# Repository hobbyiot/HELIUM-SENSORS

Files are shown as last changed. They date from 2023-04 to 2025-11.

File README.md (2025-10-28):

# HELIUM-SENSORS
## Helium IoT Network Sensor Development board | [H2S-Dev V1.2](https://github.com/hobbyiot/HELIUM-SENSORS/tree/main/H2S-Dev%20V1.2)

H2S-Dev board is a ready-to-use, Open source hardware, Arduino compatible, LoRaWAN Helium network sensor development board. It is capable of implementing a number of sensor and positioning applications. The board is mainly targeted to makers and hobbyists.

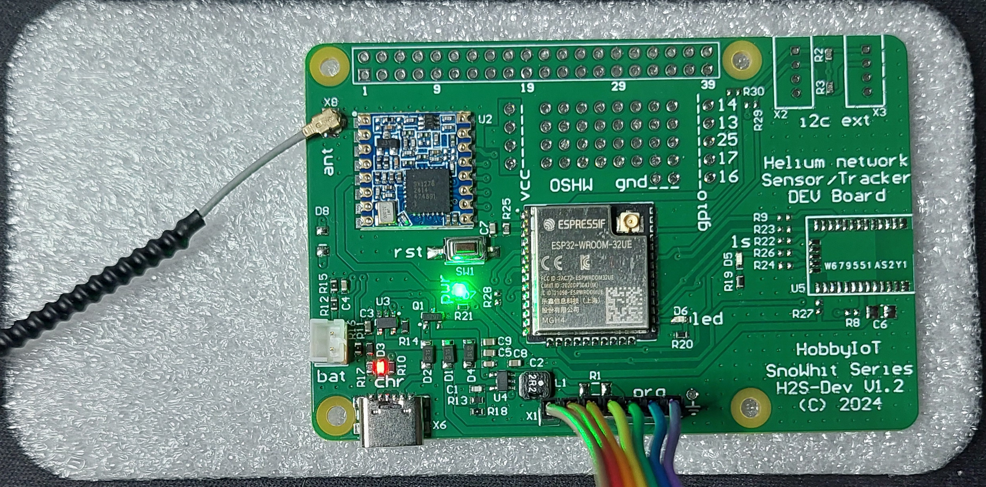
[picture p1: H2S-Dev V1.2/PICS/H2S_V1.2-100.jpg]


H2S-Dev board key features and flexible assembly options including ESP32 and SX1276 LoRa worldwide modules as well as optional GNSS. A practical powering circuitry is implemented that is capable of powering the board from the programming interface, USB-C and/or RPi compatible connector. The LiPo battery controller also charges the battery connected. The soldering area and I2C extensions allow wiring of sensors and connecting devices via I2C interfaces.

The most recent version of the Helium IoT Network Sensor Development board (H2S-Dev) is V1.2

https://github.com/hobbyiot/HELIUM-SENSORS/tree/main/H2S-Dev%20V1.2

---

### [This project was sponsored by PCBWay in 2024](https://github.com/hobbyiot/HELIUM-SENSORS/blob/main/README.md#this-project-was-sponsored-by-pcbway).

### [Levcoin donations are welcome, Bitcoin (BTC) and Helium (HNT) are accepted](https://github.com/hobbyiot/HELIUM-SENSORS/blob/main/README.md#crypto-donations).

---

H2S-Dev board is built around ESP32 MCU module and LoRaWAN SX1276 based radio module, supporting worldwide radio frequency bands, I2C standard interfaces for connecting various sensors and the relatively cheap integrated GNSS module with small chip antenna on it.

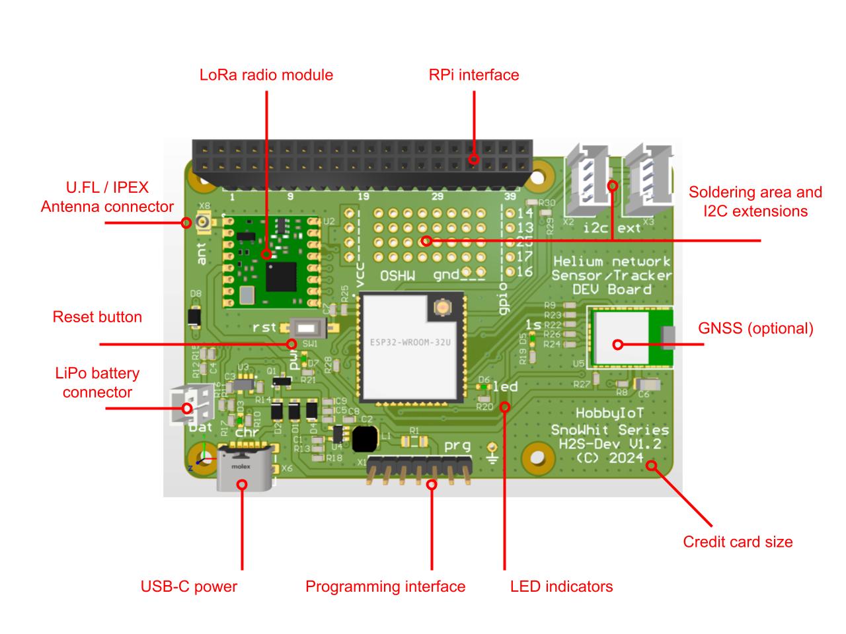
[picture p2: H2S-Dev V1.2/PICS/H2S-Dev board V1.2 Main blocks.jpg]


The development board also incorporates a standard 7-pin ESP32 serial programming interface to use with any compatible Serial to USB adapter. Set of LED indicators - Power, “1 second” GNSS, Charging and General purpose LEDs are on board for indicating certain activities. USB-C and LiPo battery sockets are available for dual powering with charging circuitry and battery level sensing line routed to a CPU GPIO pin. There is also a development area grid - holes matrix area (4 rows x 8 holes each, 0.1 inch / 2.54 mm pitch) with power and ground points nearby for adding sensors, interfaces, and add-ons. Several GPIOs are routed close to the matrix area.

### Technical parameters
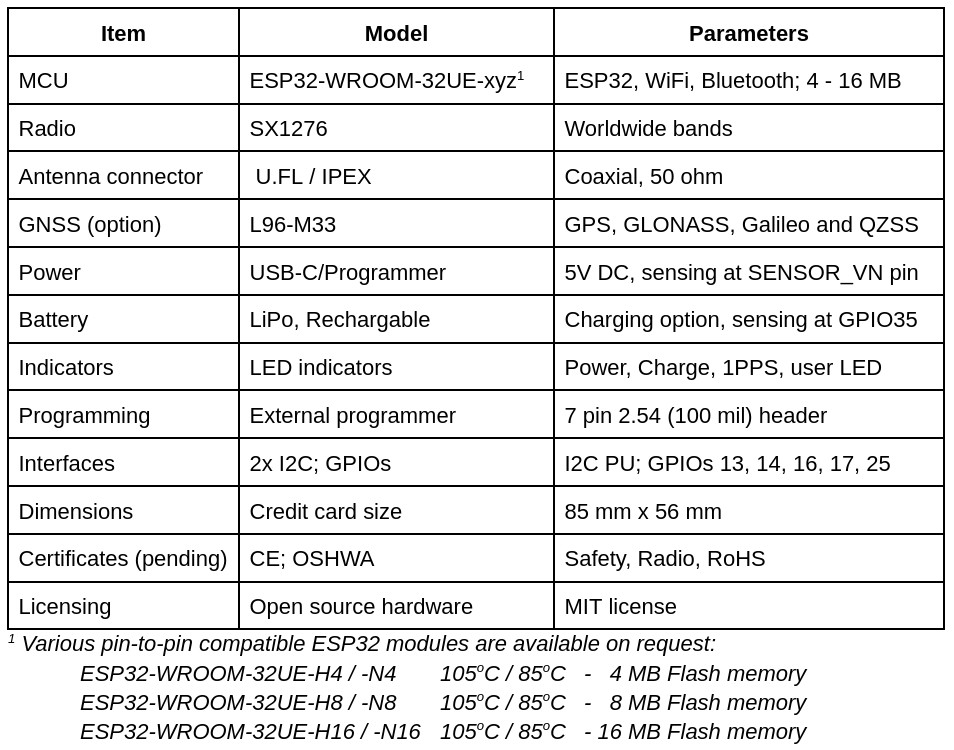
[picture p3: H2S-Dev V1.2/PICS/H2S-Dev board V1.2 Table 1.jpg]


### Circuit schematic
The circuit schematic of the Helium IoT Network Sensor Development board (H2S-Dev V1.2) is shown in the picture below. Central area presents the MCU and optional GNSS module together with the LoRa radio module and antenna connector.

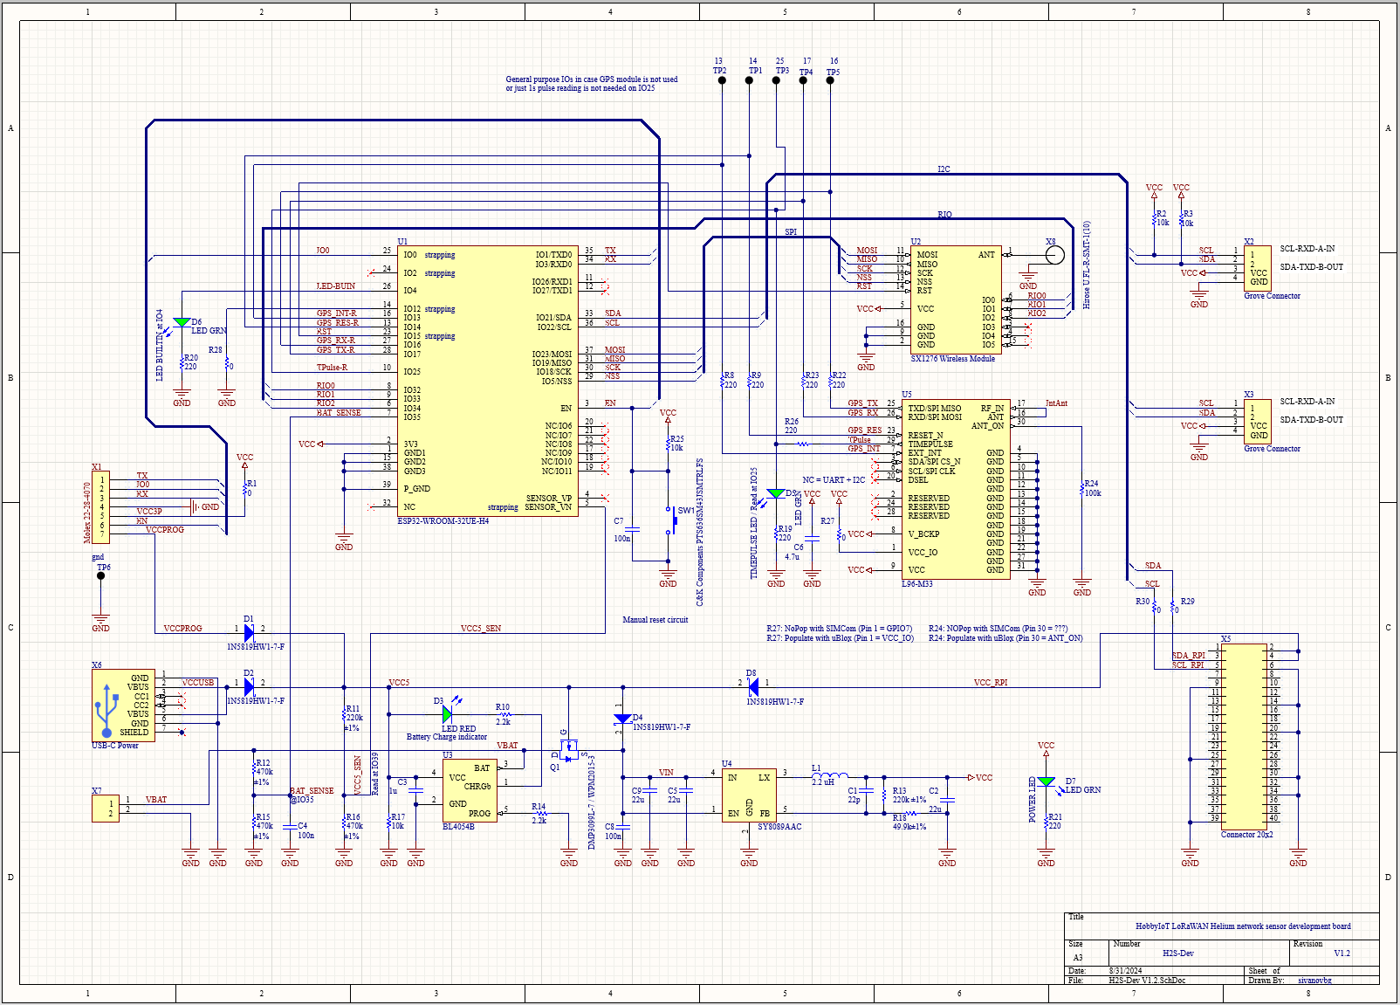
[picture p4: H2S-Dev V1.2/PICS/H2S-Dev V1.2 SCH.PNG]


On the left the mandatory I/O interface connectors are situated. Right part consists of the optional connectors. On the bottom part of the sheet the battery input and charging circuitry are placed together with the DC/DC converter responsible for generating the supply voltage for the entire design. LED indicators and a Reset switch are placed according to their corresponding function.

The schematic is drawn on a A3 standard page. Detailed schematic in PDF format: [H2S-Dev V1.2 Schematic](https://github.com/hobbyiot/HELIUM-SENSORS/blob/main/H2S-Dev%20V1.2/HW/H2S-Dev%20V1.2%20Schematic.pdf)

### Printed Circuit board

The printed circuit board (PCB) of the Helium IoT Network Sensor Development board (H2S-Dev V1.2) is designed to use a standard FR-4 1.6 mm 2-layer material for production.

H2S-Dev V1.2 Top Layer     |  H2S-Dev V1.2 Bottom Layer
:-------------------------:|:-------------------------:
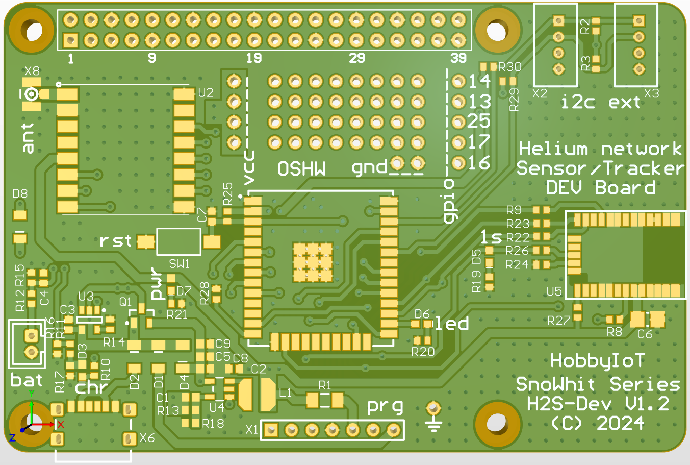
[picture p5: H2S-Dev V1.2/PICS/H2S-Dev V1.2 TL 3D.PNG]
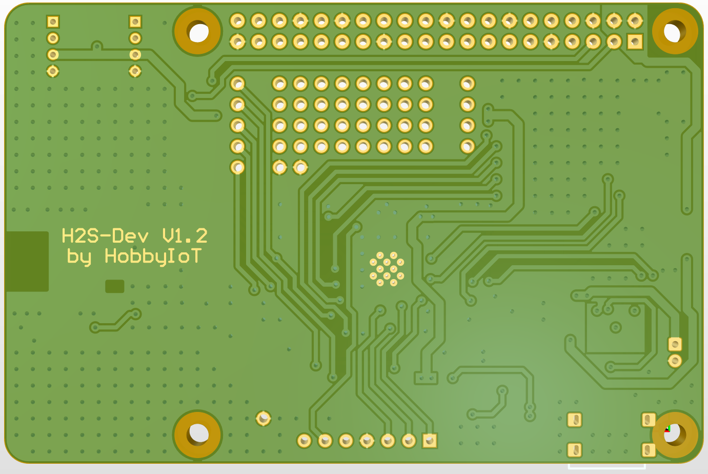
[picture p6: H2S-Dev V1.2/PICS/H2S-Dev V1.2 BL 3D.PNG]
  |  

Main parts are situated for convenient operation and minimal interference between radios implemented. The LoRa module pin 1 to U.FL antenna small trace is routed with a special attention to ensure the 50 ohm impedance requirement of that trace. The GNSS module is far away, on the other edge of the board, and it is surrounded by solid copper regions on both top and bottom copper layers according to the recommendations for proper reception of the satellite signals by the small chip antenna.

The JST battery connector and USB-C power socket are situated on the down left of the board close to the corresponding circuitry. Programming interface is a 7-pin header for connecting a suitable module to burn a software sketch into the MCU via serial interface.

On the top of the board 2x20 connector and Groove compatible footprints are located. Both of them carry powering and I2C interfaces.

### H2S-Dev board V1.2 assembly variants


### H2S-Dev board V1.2 Arduino code example

This example code in (H2S-DEV-THS-V0.1.ino) sends a valid LoRaWAN packet over The Helium network with a payload containing temperature and humidity data as they are read from a DHT11 sensor, connected to GPIO13 using frequency and encryption settings according your region.

More information: https://github.com/hobbyiot/HELIUM-SENSORS/tree/main/H2S-Dev%20V1.2/SW

The hardware of the Helium IoT Network Sensor Development board V1.2 is designed as an open source project in the Altium Circuit Maker environment. To access the project follow the links below.

https://workspace.circuitmaker.com/Projects/Details/sivanovbg/H2S-Dev-V12

https://365.altium.com/files/AC741A32-A420-4803-868D-E6CB6756A587

---

#### This project was sponsored by PCBWay.

#### They offer a turnkey service to manufacture and assemble your printed circuit boards! The whole operation is fast and reliable since every single step is agreed between the customer and the responsible people from the factory. Every one detail is discussed as the components and materials used are agreed on at a high professional level.
#### Ordering of the boards and assembly service is easy to use and fully automated through the PCBWay website and is conducted smoothly. The forwarding options are fast and flexible to have your prototypes on time!

#### I am quite impressed with the way of work and communication with the PCBWay team. The communication is fast and focused on the customer's needs. I also found PCBWay conducts various contests and grows an open source hardware community! There is even a possibility to review and order an open source project, included by a developer on the PCBWay store!

#### Thank you, PCBWay and your friendly team! I hope I will keep working with!

---

### And one more thing… Technologies and services are important, but the most important are people you are working with.

---

### Crypto donations

Crypto | Wallet address
:-------------------------------:|:----------------------------------------------------------------------:
[Levcoin](https://levcoin.net/) | <small>bg2HVDv6r9VhCi2fR8QeBy5VAgbcav7YY3yypi6ugYoBFXgFmqjQGKWjm7LZrsRQx488v58UjnYXRNdQKU5vjsiA2Yj1kNtYZ</small>
Bitcoin (BTC) | bc1q0l2zv2ayns5ppz6v9xnggkjyskdt0ywgk6zsck
Helium (HNT) | 9Un8EUQdXY53rSst26B5tufz9FUZbhcfqTYNMr4AuATh

---

https://www.pcbway.com/ | https://www.hobbyiot.net/
:----------------------------:|:------------------------------:
https://x.com/HobbyIoT | https://www.patreon.com/HobbyIoT

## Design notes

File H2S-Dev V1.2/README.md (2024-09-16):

# Helium IoT Network Sensor Development board | H2S-Dev V1.2
## Main changes and improvements

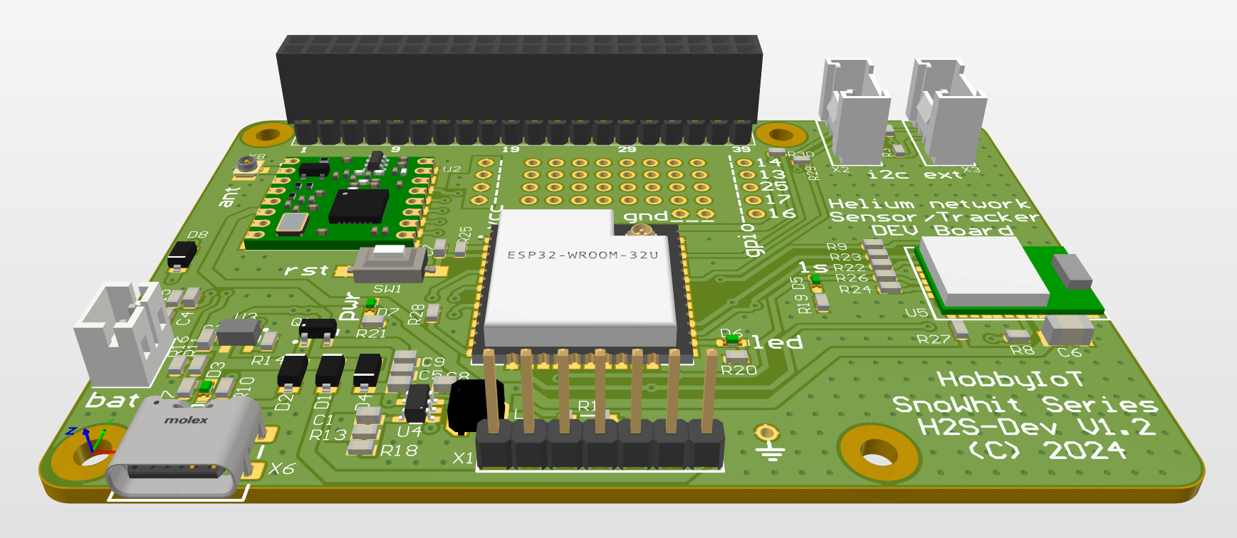
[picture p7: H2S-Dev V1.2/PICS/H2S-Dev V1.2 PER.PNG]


- A U.FL connector has been replaced the fixed LoRa spring antenna to improve the flexibility for the developers to connect most suitable antenna according the radio power and frequency requirements;

- A Basic variant of the development board has been defined as a cheap version of the PCB to improve cost effectiveness and design flexibility;

- A Full variant of the development board is now including GNSS module that gives the development of a Helium based GNSS tracking device a kick start to test the application

The project targets a LoRaWAN device - Helium IoT Network Sensor Development board (H2S-Dev) product with GNSS tracking option for primary usage with the LoRaWAN based Helium network. The board is mainly targeted to makers and hobbyists.

It’s built around ESP32 MCU module and LoRaWAN SX1276 based radio module, supporting worldwide radio frequency bands, I2C standard interfaces for connecting various sensors and the relatively cheap integrated GNSS module with small chip antenna on it. The development board also incorporates a standard 7-pin ESP32 serial programming interface to use with any compatible Serial to USB adapter. Set of LED indicators - Power, “1 second” GNSS, Charging and General purpose LEDs are on board for indicating certain activities. USB-C and LiPo battery sockets are available for dual powering with charging circuitry and battery level sensing line routed to a CPU GPIO pin. There is also a development area grid - holes matrix area (4 rows x 8 holes each, 0.1 inch / 2.54 mm pitch) with power and ground points nearby for adding sensors, interfaces, and add-ons. Several GPIOs are routed close to the matrix area.
#
More information: [H2S-Dev board V1.2 Hardware description and features](https://github.com/hobbyiot/HELIUM-SENSORS/blob/main/H2S-Dev%20V1.2/H2S-Dev%20board%20V1.2%20Hardware%20description%20and%20features.pdf)

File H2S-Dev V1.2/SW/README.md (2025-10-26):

## H2S-Dev with DHT11 temperature and humidity sensor example

The most recent example code in ([H2S-DEV-THS-V0.5.ino](https://github.com/hobbyiot/HELIUM-SENSORS/blob/main/H2S-Dev%20V1.2/SW/H2S-DEV-THS-V0.5.ino)) sends a valid LoRaWAN packet over The Helium network with a payload containing temperature and humidity data as they are read from a DHT11 sensor, connected to GPIO#13 using frequency and encryption settings according your region.

You can solder and wire the DHT11 sensor within the H2S-Dev soldering area or just use Crowtail connector directly to the H2S-Dev board using the [Elecrow DHT11 sensor module](https://www.elecrow.com/crowtail-temperature-humidity-sensor-p-1229.html).

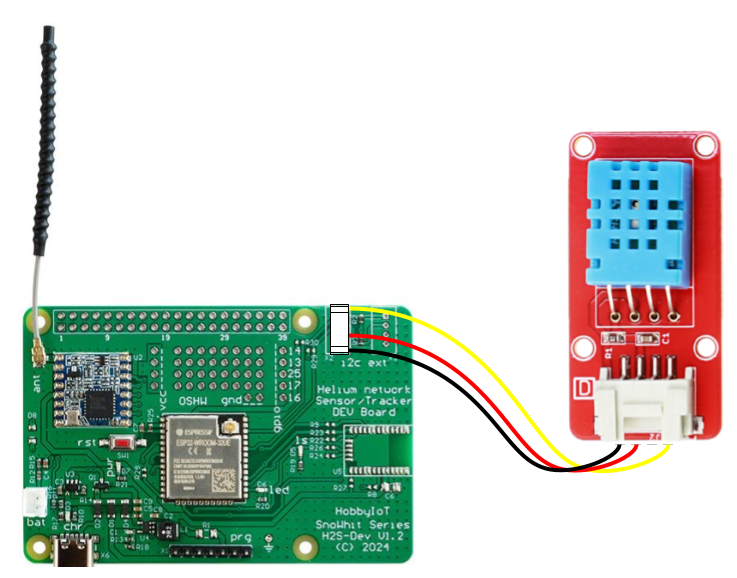
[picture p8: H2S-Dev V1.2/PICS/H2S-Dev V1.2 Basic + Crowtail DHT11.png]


The data format and the JSON script for decoding it will be soon described in separate article in the project's GitHub (https://github.com/hobbyiot/HELIUM-SENSORS)

You can also direct the received data via Helium console directly to a Google sheet!

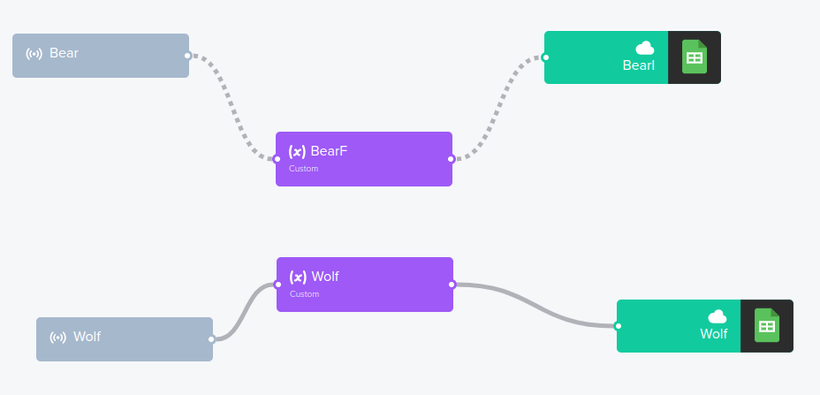
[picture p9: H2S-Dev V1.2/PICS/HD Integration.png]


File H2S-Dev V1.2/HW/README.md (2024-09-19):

# Helium IoT Network Sensor Development board | H2S-Dev V1.2
## Hardware review

### Circuit schematic

The circuit schematic of the Helium IoT Network Sensor Development board (H2S-Dev V1.2) is shown on the picture below. Central area presents the MCU and optional GNSS module together with the LoRa radio module and antenna connector.



On the left the mandatory I/O interface connectors are situated. Right part consists the optional connectors. On the bottom part of the sheet the battery input and charging circuitry are placed together with the DC/DC converter responsible for generating the supply voltage for the entire design. LED indicators and a Reset switch are placed according to their corresponding function.

The schematic is drawn on a A3 standard page. Detailed schematic in PDF format: [H2S-Dev V1.2 Schematic](https://github.com/hobbyiot/HELIUM-SENSORS/blob/main/H2S-Dev%20V1.2/HW/H2S-Dev%20V1.2%20Schematic.pdf)

### Printed Circuit board

The printed circuit board (PCB) of the Helium IoT Network Sensor Development board (H2S-Dev V1.2) is designed to use a standard FR-4 1.6 mm 2-layer material for production.

H2S-Dev V1.2 Top Layer     |  H2S-Dev V1.2 Bottom Layer
:-------------------------:|:-------------------------:
  |  

Main parts are situated for convenient operation and minimal interference between radios implemented. The LoRa module pin 1 to U.FL antenna small trace is routed with a special attention to ensure the 50 ohm impedance requirement of that trace. The GNSS module is far away, on the other edge of the board, and it is surrounded by solid copper regions on both top and bottom copper layers according the recommendations for proper reception of the satellite signals by the small chip antenna.

JST battery connector and USB-C power socket are situated on the down left of the board close to the corresponding circuitry. Programming interface is a 7-pin header for connecting a suitable module to burn a software sketch into the MCU via serial interface.

On the top of the board 2x20 connector and Groove compatible footprints are located. Both of them carry powering and I2C interfaces.

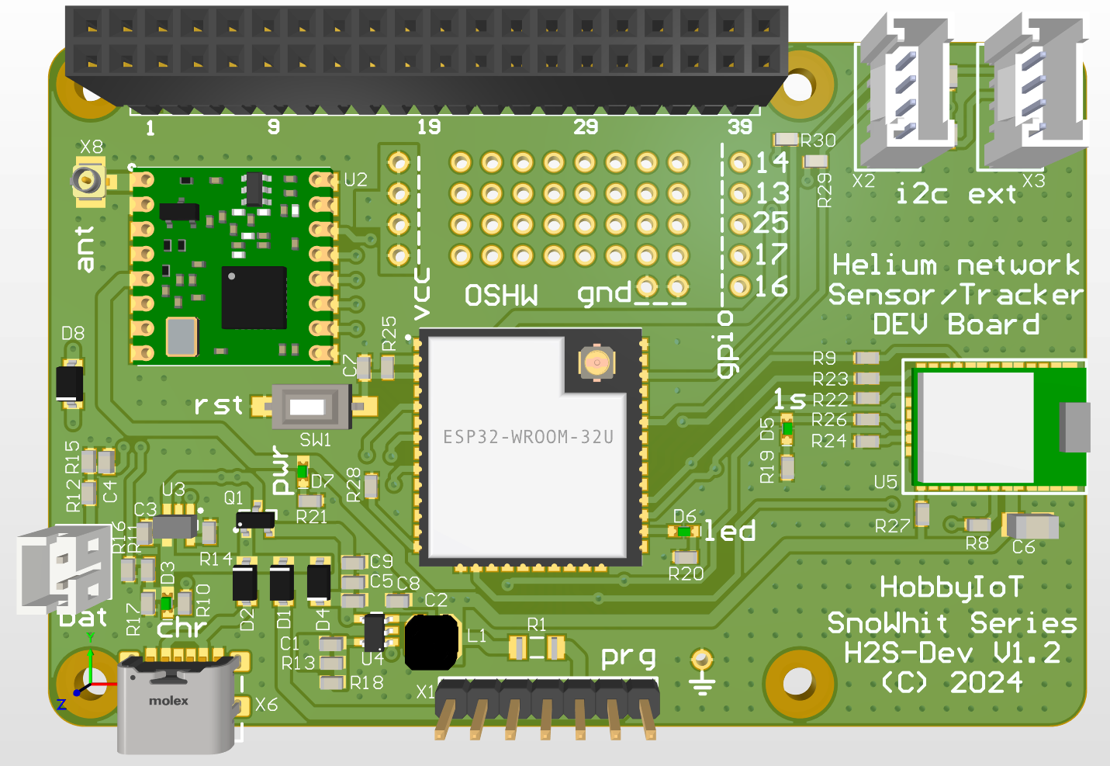
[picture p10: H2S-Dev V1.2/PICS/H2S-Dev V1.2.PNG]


The size, mechanics and 2x20 connector nets of the Helium IoT Network Sensor Development board V1.2 comply with the recent RaspberryPi specifications.

#
The hardware of the Helium IoT Network Sensor Development board V1.2 is designed as an open source project in the Altium Circuit Maker environment. To access the project follow the links below.

https://workspace.circuitmaker.com/Projects/Details/sivanovbg/H2S-Dev-V12

https://365.altium.com/files/AC741A32-A420-4803-868D-E6CB6756A587
#
More information: [H2S-Dev board V1.2 Hardware description and features](https://github.com/hobbyiot/HELIUM-SENSORS/blob/main/H2S-Dev%20V1.2/H2S-Dev%20board%20V1.2%20Hardware%20description%20and%20features.pdf)

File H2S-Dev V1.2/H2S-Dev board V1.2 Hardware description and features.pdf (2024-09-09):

### H2S-Dev board

LoRaWAN Helium network sensor development board V1.2
Hardware description and features

Introduction

H2S-Dev board is a ready-to-use, Open source hardware, Arduino compatible, LoRaWAN Helium network sensor development board. It is capable of implementing a number of sensor and positioning applications.

H2S-Dev board key features and flexible assembly options including ESP32 and SX1276 LoRa worldwide modules as well as optional GNSS. A practical powering circuitry is implemented that is capable of powering the board from the programming interface, USB-C and/or RPi compatible connector. The LiPo battery controller also charges the battery connected. The soldering area and I2C extensions allow wiring of sensors and connecting devices via I2C interfaces.

H2S-Dev board is following the Raspberry Pi form factor (credit card size) with mounting holes and 40-pin connector including power and I2C traces for further development.

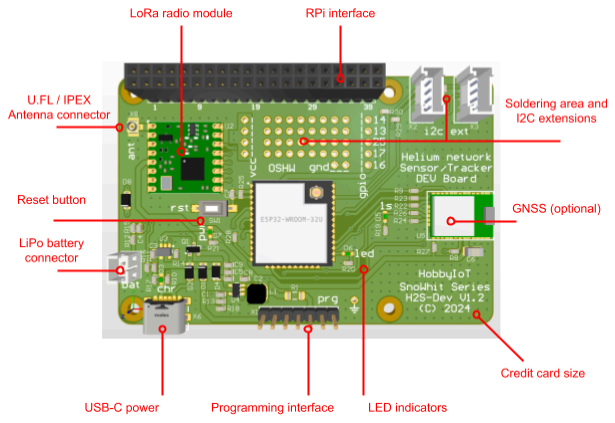
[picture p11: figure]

More information: https://www.hobbyiot.net | 1

Hardware description

H2S-Dev board V1.2 is the new upcoming improved version with flexible assembly variants. It contains ESP32, LoRa radio with 50 ohm U.FL/IPEX connector for various frequency bands, optional GNSS, powering options and interfaces resulting in a rich set of features. That open source hardware platform is ready for one to quickly set up an application, connect sensors and test IoT data transfer over the Helium LoRaWAN network.

ESP32 WROOM MCU runs the device application software. It controls the LoRa radio module via SPI interface and I/O signals required. MCU also connects to the optional GNSS module via UART interface and control lines. When GNSS is not used, a number of GPIO lines are free for connecting additional sensors. These lines are routed close to the development area of the board. WiFi and Bluetooth are available with an external antenna. Pin-to-pin compatible modules are available up to the application requirements including H4/N4 (4 MB Flash) up to H16/N16 (16 MB Flash).

The LoRa Radio module establishes the connection to the Helium LoRaWAN network. It is built around SX1276 IC and connects to the MCU via SPI interface as described. Radio module requires an antenna to operate and the antenna should be in place before powering on the module to prevent radio amplifier damage. Size and type of the antenna depends on the gain required and the specific frequency band for the region. Antenna connector type is U.FL / IPEX.

GNSS module (optional) - when assembled, the GNSS module connects to the MCU via UART interface. Once locked to satellites it provides date/time and positioning information to the system and the 1PPS LED will flash every one second. The dev board PCB topology is designed according to the GNSS module recommendations to ensure proper signal reception by the onboard chip-antenna.

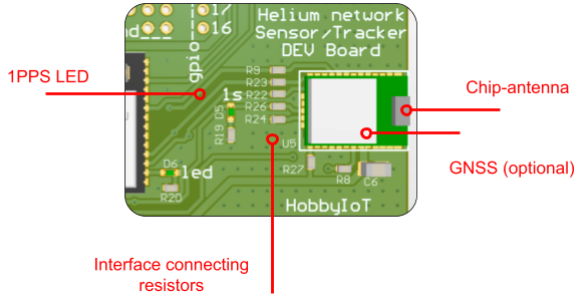
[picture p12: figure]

More information: https://www.hobbyiot.net | 2

Soldering area and I2C extensions - That area is especially dedicated to developers. It contains 4 rows by 8 columns of THT mounting holes with 2.54 mm (100 mil) spacing as well as I2C extensions.

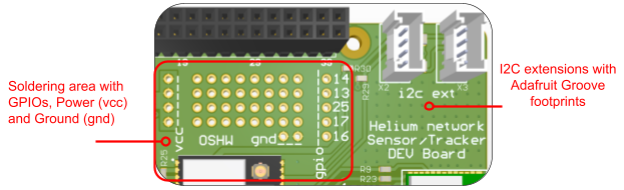
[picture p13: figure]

One can solder connection headers, small sensors and any other external devices into that area. Close to that pattern a 3.3V power (vcc) and Ground (gnd) connection points are available. Also, several MCU I/O signals are routed around that area for easy interfacing with the MCU.

I2C extensions (i2c ext) provide an I2C interface together with 3.3V and GND. Footprint and pinout are compatible with Adafruit Groove specifications. 4.7 k pull up resistors are populated on the dev board.

Programming interface - these pins are used to program and debug the software into the dev board. Pinout is compatible with the Olimex ESP32 programmer board as shown below. Using such a programmer the ESP32 is entering programing mode automatically when the upload attempt is initiated from the programming environment.

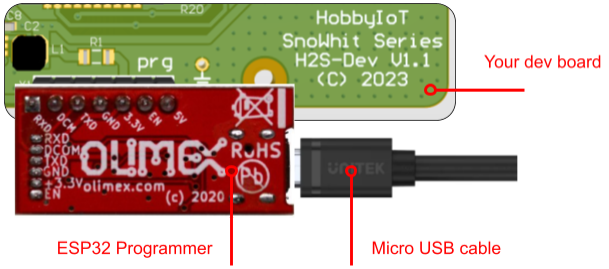
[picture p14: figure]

More information: https://www.hobbyiot.net | 3

Important notice! When connecting the programmer, first connect it to the dev board and after that connect the micro usb cable as shown in the picture below.

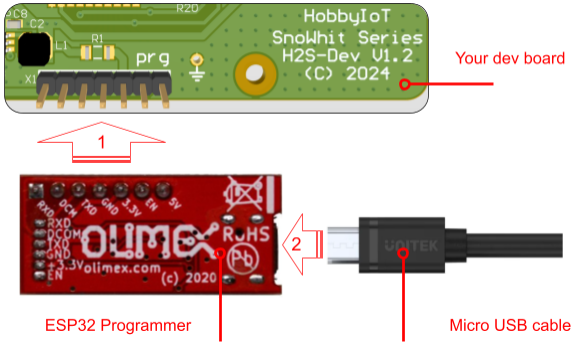
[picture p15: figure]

LiPo battery connector JST type, 2-pole socket is used to connect a LiPo battery to independently power the dev board. The circuitry behind is built around the LiPo battery controller BL4054B and DC/DC converter SY8088AAC and will automatically switch to battery power when other sources are down. Connected battery will also be charged if any of the other power sources are connected. Battery voltage can be read by the user software at GPIO35 and the external voltage presence trigger level is available at GPIO39 via resistor dividers.

USB-C power - 5V DC power only input using USB-C standard cable.

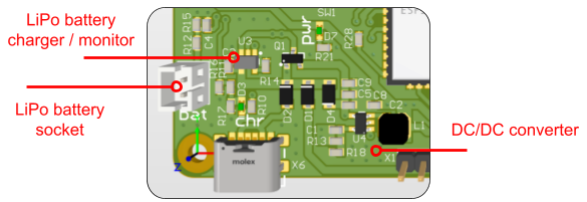
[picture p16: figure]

More information: https://www.hobbyiot.net | 4

RPi interface - As a future use the dev board could be connected and powered as a Raspberry Pi HAT. I2C, power and GND lines are routed to that connector.

Reset button - Used to perform hardware reset of the board.

Credit card size - The dev board dimensions are 85 mm x 56 mm and carries 4 mounting holes compatible with Raspberry Pi.

Technical parameters

Item | Model | Parameters
MCU | ESP32-WROOM-32UE-xyz 1 | ESP32, WiFi, Bluetooth; 4 - 16 MB
Radio | SX1276 | Worldwide bands
Antenna connector | U.FL / IPEX | Coaxial, 50 ohm
GNSS (option) | L96-M33 | GPS, GLONASS, Galileo and QZSS
Power | USB-C/Programmer | 5V DC, sensing at SENSOR_VN pin
Battery | LiPo, Rechargable | Charging option, sensing at GPIO35
Indicators | LED indicators | Power, Charge, 1PPS, user LED
Programming | External programmer | 7 pin 2.54 (100 mil) header
Interfaces | 2x I2C; GPIOs | I2C PU; GPIOs 13, 14, 16, 17, 25
Dimensions | Credit card size | 85 mm x 56 mm
Certificates (pending) | CE; OSHWA | Safety, Radio, RoHS
Licensing | Open source hardware | MIT license

### 1 Various pin-to-pin compatible ESP32 modules are available on request:

ESP32-WROOM-32UE-H4 / -N4 105 oC / 85

oC - 4 MB Flash memory
ESP32-WROOM-32UE-H8 / -N8 105 oC / 85

oC - 8 MB Flash memory
ESP32-WROOM-32UE-H16 / -N16 105
| oC / 85

oC - 16 MB Flash memory

H2S-Dev board V1.2 assembly variants

Variant name | Variant description
H2S-Dev board Basic | ESP32, LoRa, no GNSS module, 5x GPIOs, 2x I2C, LED indicators
H2S-Dev board Full | ESP32, LoRa, L96-M33 GNSS module, 2x I2C, LED indicators
More information: https://www.hobbyiot.net | 5

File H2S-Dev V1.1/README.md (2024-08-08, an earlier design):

# Helium IoT Network Sensor Development board
Version 1.1

H2S-Dev V1.1

The project targets a LoRaWAN device - Helium IoT Network Sensor Development board (H2S-Dev) product with GNSS tracking option for primary usage with the LoRaWAN based Helium network. The board is mainly targeted to makers and hobbyists.
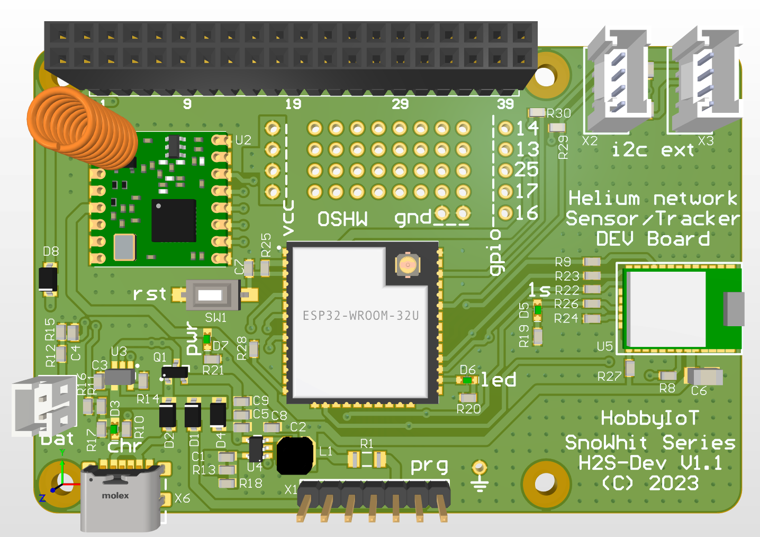
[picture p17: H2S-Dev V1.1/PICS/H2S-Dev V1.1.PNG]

It’s built around ESP32 MCU module and LoRaWAN SX1276 based radio module, supporting worldwide radio frequency bands, I2C standard interfaces for connecting various sensors and the relatively cheap integrated GNSS module with small chip antenna on it. The development board also incorporates a standard 7-pin ESP32 serial programming interface to use with any compatible Serial to USB adapter. Set of LED indicators - Power, “1 second” GNSS, Charging and General purpose LEDs are on board for indicating certain activities. USB-C and LiPo battery sockets are available for dual powering with charging circuitry and battery level sensing line routed to a CPU GPIO pin. There is also a development area grid - holes matrix area (4 rows x 8 holes each, 0.1 inch / 2.54 mm pitch) with power and ground points nearby for adding sensors, interfaces, and add-ons. Several GPIOs are routed close to the matrix area.

More information: [H2S-Dev board Hardware description and features](https://github.com/hobbyiot/HELIUM-SENSORS/blob/main/H2S-Dev%20V1.1/DOCS/H2S-Dev%20board%20Hardware%20description%20and%20features.pdf)

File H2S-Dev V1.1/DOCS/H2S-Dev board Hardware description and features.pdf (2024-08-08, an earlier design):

### H2S-Dev board

LoRaWAN Helium network sensor development board V1.1
Hardware description and features

Introduction

H2S-Dev board is a ready-to-use, Open source hardware, Arduino compatible, LoRaWAN Helium network sensor development board. It is capable of implementing a number of sensor and positioning applications.

H2S-Dev board key features include ESP32 and SX1276 LoRa modules as well as optional GNSS. A practical powering circuitry is implemented that is capable of powering the board from the programming interface, USB-C and RPi compatible connector. The LiPo battery controller also charges the battery connected. The soldering area and I2C extensions allow placing of sensors and connecting devices via I2C interfaces.

H2S-Dev board is following the Raspberry Pi form factor (credit card size) with mounting holes and 40-pin connector including power and I2C traces for further development.

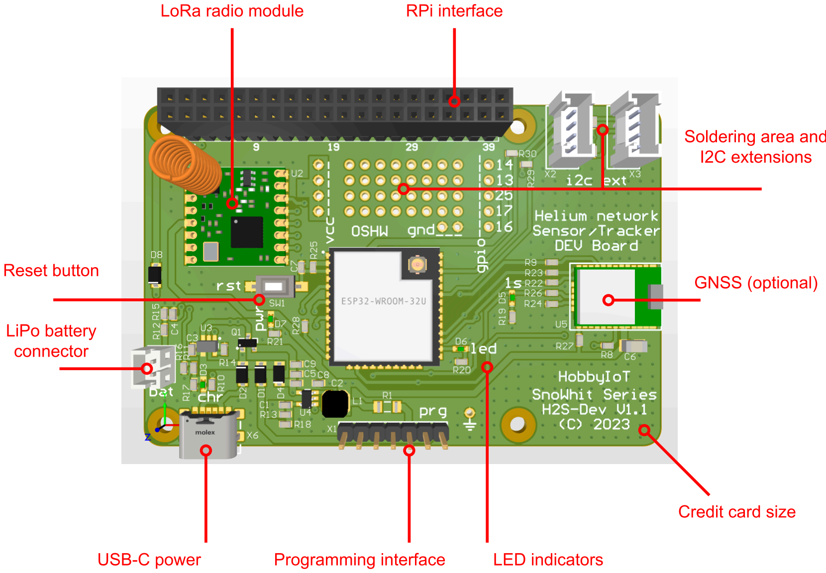
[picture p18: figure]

Hardware description

H2S-Dev board current version is V1.1. It contains ESP32, LoRa radio, optional GNSS, powering options and interfaces resulting in a rich set of features. That open source hardware platform is ready for one to quickly set up an application, connect sensors and test IoT data transfer over the Helium LoRaWAN network.

Main hardware parts are described below.

ESP32 WROOM MCU runs the device application software. It controls the LoRa radio module via SPI interface and I/O signals required. MCU also connects to the optional GNSS module via UART interface and control lines. When GNSS is not used, a number of GPIO lines are free for connecting additional sensors. These lines are routed close to the development area of the board. WiFi and Bluetooth are available with an external antenna.

The LoRa Radio module establishes the connection to the Helium LoRaWAN network. It is built around SX1276 IC and connects to the MCU via SPI interface as described. Radio module requires an antenna to operate and the antenna should be in place before powering on the module to prevent radio amplifier damage. Size and type of the antenna depends on the gain required and the specific frequency band for the region.

GNSS module (optional) - when assembled, the GNSS module connects to the MCU via UART interface. Once locked to satellites it provides date/time and positioning information to the system and the 1PPS LED will flash every one second. The dev board PCB topology is designed according to the GNSS module recommendations to ensure proper signal reception by the onboard chip-antenna.

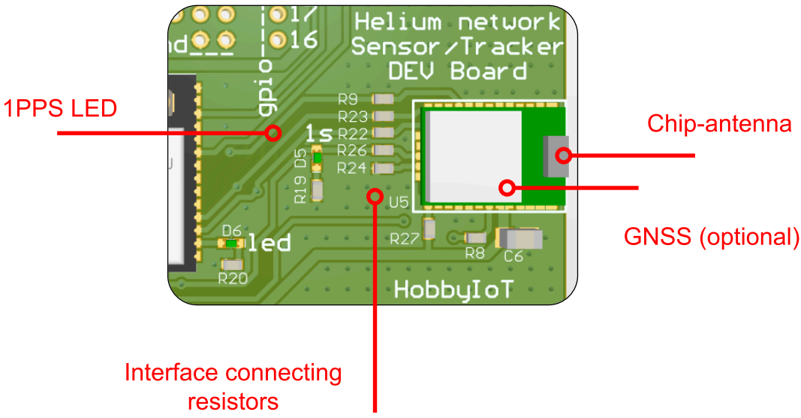
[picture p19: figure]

Soldering area and I2C extensions - That area is especially dedicated to developers. It contains 4 rows by 8 columns of THT mounting holes with 2.54 mm (100 mil) spacing as well as

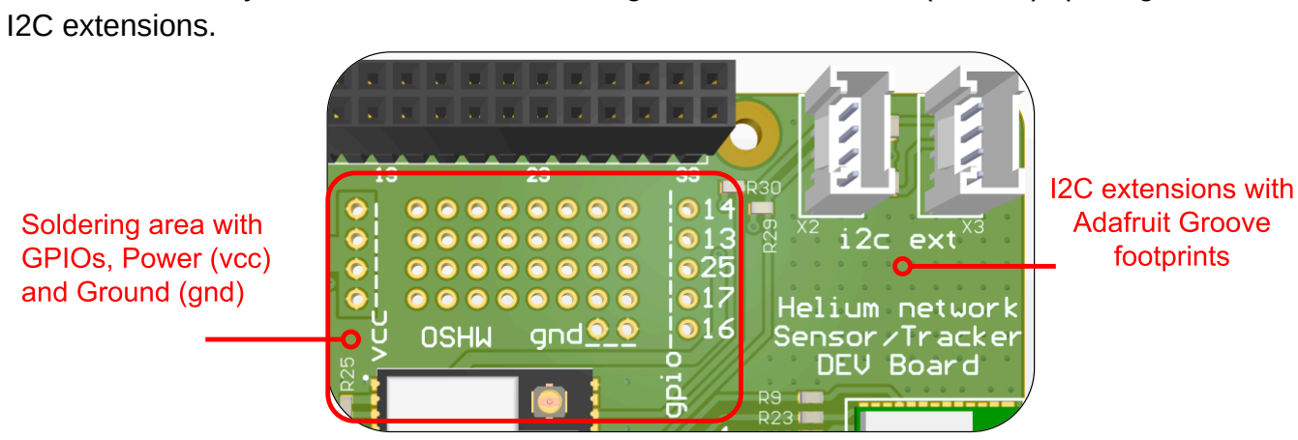
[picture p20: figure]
I2C extensions.

One can solder connection headers, small sensors and any other external devices into that area. Close to that pattern a 3.3V power (vcc) and Ground (gnd) connection points are available. Also, several MCU I/O signals are routed around that area for easy interfacing with the MCU.

I2C extensions (i2c ext) provide an I2C interface together with 3.3V and GND. Footprint and pinout are compatible with Adafruit Groove specifications. 4.7 k pull up resistors are populated on the dev board.

Programming interface - these pins are used to program and debug the software into the dev board. Pinout is compatible with the Olimex ESP32 programmer board as shown below. Using such a programmer the ESP32 is entering programing mode automatically when the upload attempt is initiated from the programming environment.

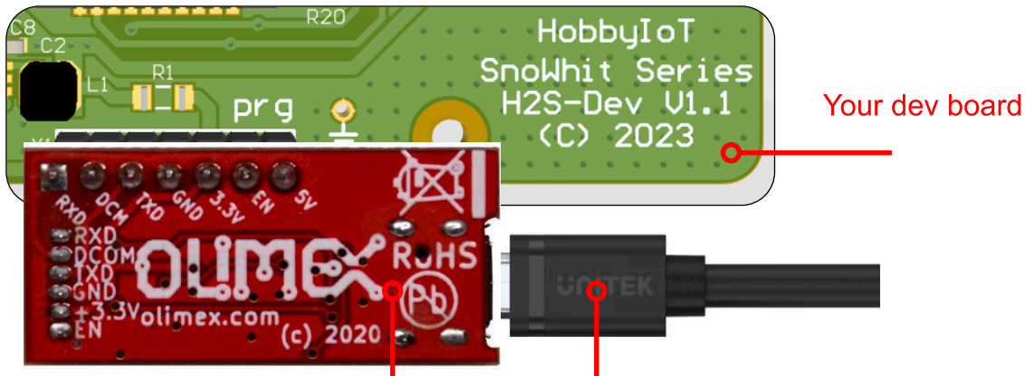
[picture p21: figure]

Important notice! When connecting the programmer, first connect it to the dev board and after that connect the micro usb cable as shown in the picture below.

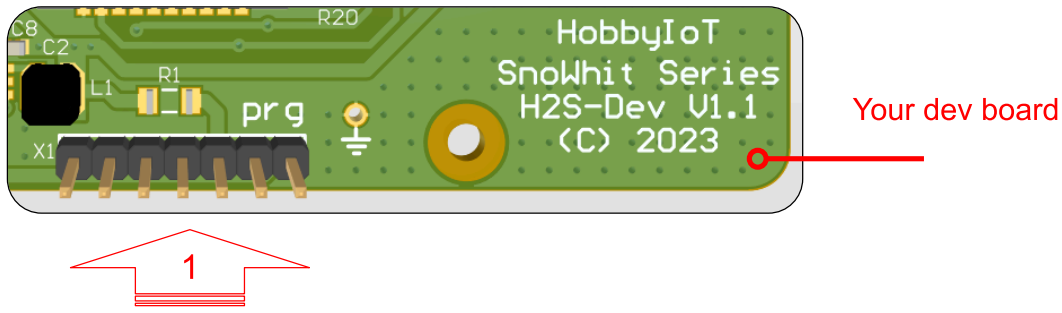
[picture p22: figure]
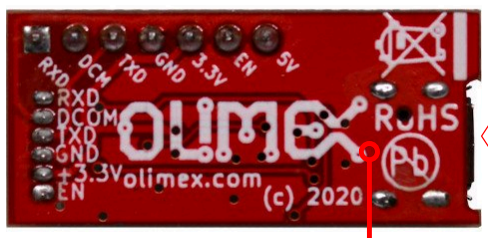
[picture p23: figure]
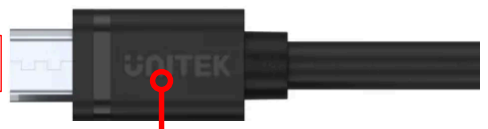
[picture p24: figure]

LiPo battery connector JST type, 2-pole socket is used to connect a LiPo battery to independently power the dev board. The circuitry behind is built around the LiPo battery controller BL4054B and DC/DC converter SY8088AAC and will automatically switch to battery power when other sources are down. Connected battery will also be charged if any of the other power sources are connected. Battery voltage can be read by the user software at GPIO35 and the external voltage presence trigger level is available at GPIO39 via resistor dividers.

USB-C power - 5V DC power only input using USB-C standard cable.

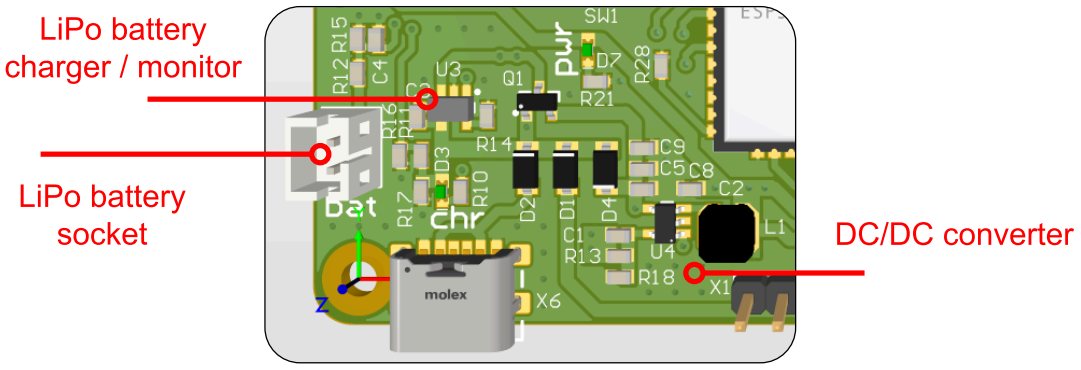
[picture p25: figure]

RPi interface - As a future use the dev board could be connected and powered as a Raspberry Pi HAT. I2C, power and GND lines are routed to that connector.

Reset button - Used to perform hardware reset of the board.

Credit card size - The dev board dimensions are 85 mm x 56 mm and carries 4 mounting holes compatible with Raspberry Pi.

Technical parameters

Item | Model | Parameters
MCU | ESP32 WROOM Series | ESP32, WiFi, Bluetooth
Radio | SX1276 with spring antenna | Worldwide bands
GNSS (option) | L96-M33 | GPS, GLONASS, Galileo and QZSS
Power | USB-C/Programmer | 5V DC
Battery | LiPo, Rechargable | Charging/sensing circuitry
Indicators | LED indicators | Power, Charge, 1PPS, user LED
Programming | External programmer | 7 pin 2.54 (100 mil) header
Interfaces | 2x I2C; GPIOs | I2C PU; GPIOs 13, 14, 16, 17, 25
Dimensions | Credit card size | 85 mm x 56 mm
Certificates (pending) | CE; OSHWA | Safety, Radio, RoHS
Licensing | Open source hardware | MIT license

More information

Github: https://github.com/hobbyiot/HELIUM-SENSORS

X/Twitter: https://x.com/HobbyIoT

Patreon: https://www.patreon.com/HobbyIoT

Web: https://www.hobbyiot.net

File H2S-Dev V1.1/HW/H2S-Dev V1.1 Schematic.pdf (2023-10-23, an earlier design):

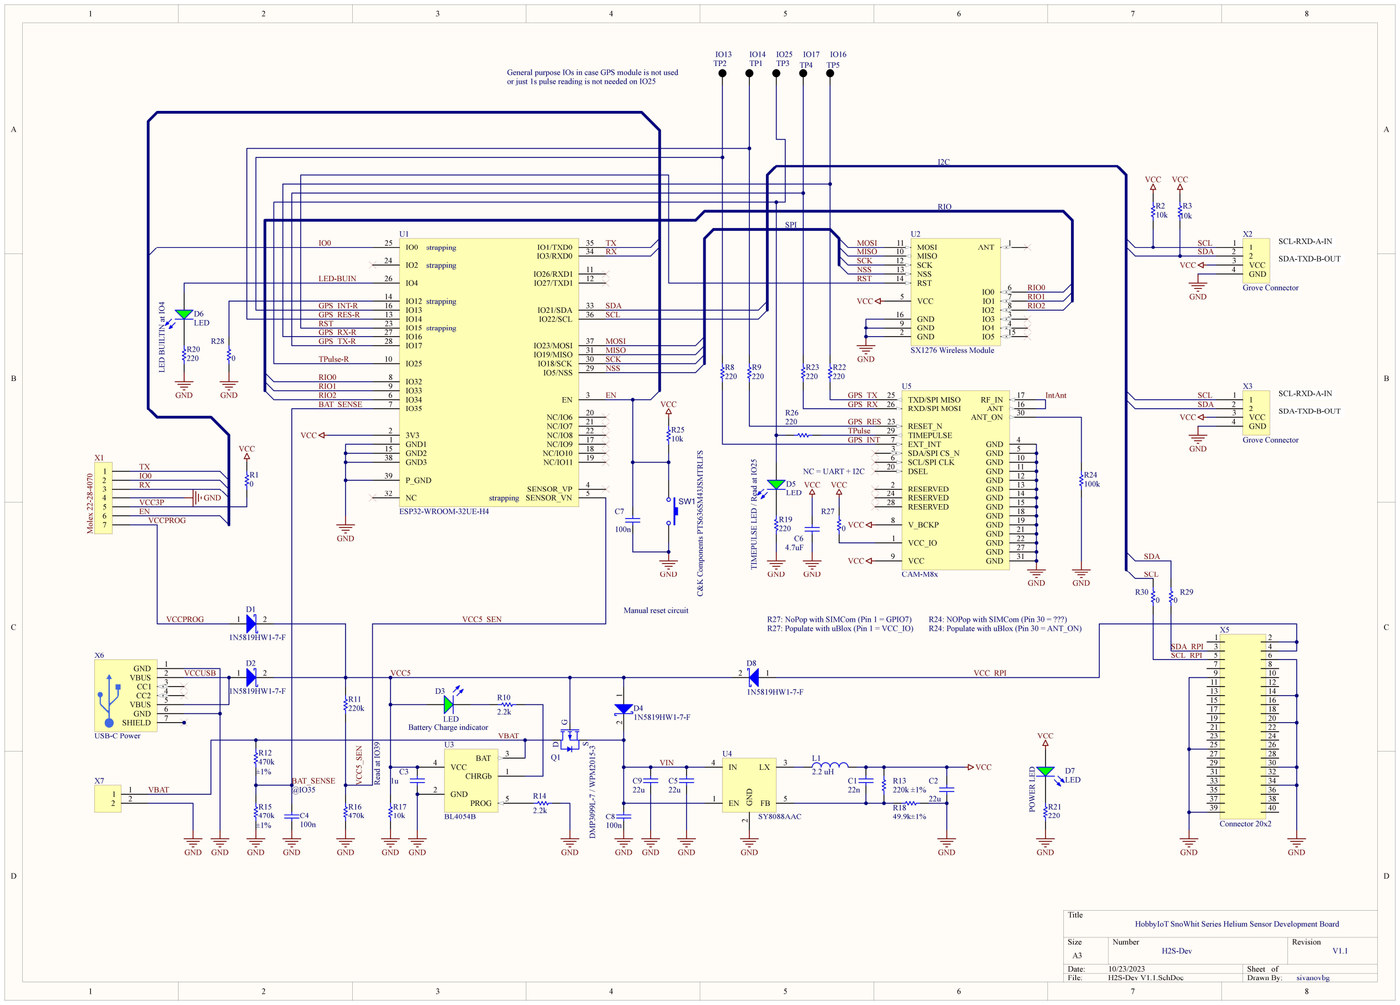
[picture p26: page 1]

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
Title

Size | Number | Revision
A3
Date: | 10/23/2023 | Sheet of
File: | H2S-Dev V1.1.SchDoc | Drawn By:
ANT | 1

GND 2

IO3 | 3
IO4 | 4

VCC 5

IO0 | 6
IO1 | 7
IO2 | 8

GND 9

MISO 10 MOSI 11

SCK 12
NSS 13
RST 14

IO5 15

GND 16

U2

SX1276 Wireless Module

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
Grove Connector

GND

VCC

MOSI
MISO
SCK
NSS
RST
RIO0
RIO1
RIO2

MOSI
MISO
SCK
NSS
RIO0

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
SDA-TXD-B-OUT

SCL-RXD-A-IN

TX

RX

IO0

EN

IO0 | TX RX

EN

R2
10k

R3
10k

VCC VCC

CHRGb 1

GND 2

BAT 3
VCC 4

PROG 5

U3

BL4054B

GND

VCCUSB | 1 | 2

D2

1N5819HW1-7-F | 1 2

D4
1N5819HW1-7-F

GND

R14
2.2k

GND

1

1
2

2

X7

GND

VBAT

GND

VCC

±1%

R18
49.9k

±1%

R13
220k

GND

VIN

GND D

S G

Q1 | DMP³⁰⁹⁹L⁻⁷ / WPM²⁰¹⁵⁻³ | IN 4
EN 1 | GND

2

LX | 3
FB | 5

U4

SY8088AAC

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
Grove Connector
GND

VCC

SDA

SCL

SDA-TXD-B-OUT

SCL-RXD-A-IN

VBAT

±1%

R12
470k

±1%

R15
470k

R11
220k

R16
470k

GND GND

BAT_SENSE

BAT_SENSE

GND

# VCC5 VCC⁵_SEN

VCC5_SEN

@IO35

Battery Charge indicator

7

6

5

4

3

2

1

# X1 Molex 22⁻28⁻4070

1 2

D1

1N5819HW1-7-F

VCCPROG

VCCPROG

VCC

GND VCC3P

VCC

GND | 1
VBUS | 2
CC1 | 3
CC2 | 4
VBUS | 5
GND | 6
SHIELD | 7

X6

USB-C Power

C4
100n

C1
22n

R17
10k

GND

R10
2.2k

D3

LED Read at IO³⁹

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
GND1 1

3V3 2

EN | 3
SENSOR_VP | 4
SENSOR_VN | 5

IO34 6
IO35 7

IO32 8
IO33 9

IO25 10

IO26/RXD1 | 11
IO27/TXD1 | 12

IO14 13

IO12 14

GND2 15

IO13 16

NC/IO9 | 17
NC/IO10 | 18
NC/IO11 | 19
NC/IO6 | 20
NC/IO7 | 21
NC/IO8 | 22

IO15 23

IO2 24

IO0 25

IO4 26

IO16 27
IO17 28
IO5/NSS | 29 IO18/SCK | 30 IO19/MISO | 31

NC 32

IO21/SDA | 33
IO3/RXD0 | 34 IO1/TXD0 | 35
IO22/SCL | 36
IO23/MOSI | 37

GND3 38

P_GND 39

U1

ESP32-WROOM-32UE-H4

TXD/SPI MISO 25

VCC 9

VCC_IO 1

V_BCKP 8

RXD/SPI MOSI 26

RESET_N 23
TIMEPULSE 29
EXT_INT 7
SDA/SPI CS_N 3
SCL/SPI CLK 6
DSEL 20

RESERVED 2
RESERVED 24
RESERVED 28
RF_IN | 17
GND | 4
GND | 5
GND | 10
GND | 11
GND | 12
GND | 13
GND | 14
GND | 15
GND | 18
GND | 19
GND | 21
GND | 22
GND | 27
GND | 31
ANT | 16
ANT_ON | 30

U5

CAM-M8x
GND

NC = UART + I2C

VCC

VCC

strapping

strapping

strapping

strapping

strapping

GND

RIO1
RIO2 | GPS_TX
| GPS_RX

R1
0

GPS_RX-R
GPS_TX-R

R22
220

R23
220

C6
4.7uF

GND

VCC

GND

TPulse

R26
220

GND

TPulse-R

LED-BUIN

R8
220

R9
220

GPS_RES

GPS_INT

I2C

RIO

SPI

GPS_RES-R

GPS_INT-R LED BUILTIN at IO⁴ | POWER LED TIMEPULSE LED / Read at IO²⁵

IntAnt

R24
100k

GND

C8
100n

C5
22u

C9
22u

GND GND

C2

22u

L1

### 2.2 uH

HobbyIoT SnoWhit Series Helium Sensor Development Board

H2S-Dev | V1.1

sivanovbg

R25
10k

VCC

R27

0

VCC

R27: NoPop with SIMCom (Pin 1 = GPIO7) R27: Populate with uBlox (Pin 1 = VCC_IO)

R24: NOPop with SIMCom (Pin 30 = ???) R24: Populate with uBlox (Pin 30 = ANT_ON)

C3
1u

GND

C7

100n

Manual reset circuit

R28

0

GND

TP2

IO13
TP1

IO14
TP3

IO25
TP4

IO17
TP5

IO16

General purpose IOs in case GPS module is not used or just 1s pulse reading is not needed on IO25

# SW1 C&K Components PTS⁶³⁶SM⁴³JSMTRLFS

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
Connector 20x2

2 1

D8

1N5819HW1-7-F

VCC_RPI

GND | GND

R29
0

R30
0

SDA_RPI
SCL_RPI

SCL

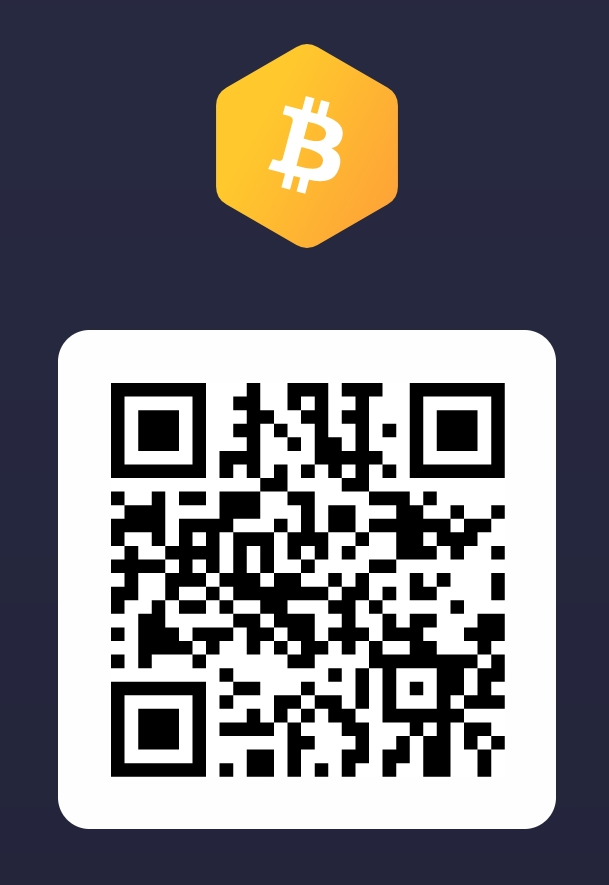
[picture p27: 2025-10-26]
.github/BTC_SI_QR.png

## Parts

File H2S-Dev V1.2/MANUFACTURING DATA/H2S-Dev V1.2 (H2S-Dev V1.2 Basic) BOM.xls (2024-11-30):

Item # | Designator | Qty | Manufacturer | Purchase Mfg Part # | Description / Value | Mounting Type
1 | C3 | 1 |  | TCC0603X7R105K160CT | Capacitor ceramic 1u 16V 10% X7R 0603 1u | Surface Mount
2 | C1 | 1 |  | CC0603KRNPO9BN220 | Capacitor ceramic 22p 6.3V 10% C0G 0603 22p | Surface Mount
3 | C2, C5, C9 | 3 |  | GMC10X5R226K6R3NT | Capacitor ceramic 22u 6.3V 10% C0G 0603 22u | Surface Mount
4 | C4, C7, C8 | 3 |  | TCC0603X7R104K160CT | Capacitor ceramic 100n 16V 10% X7R 0603 100n | Surface Mount
5 | U3 | 1 |  | BL4054B-42TPTRN | Charger Li-Ion Battery 800mA SMD SOT23-5 PN BL4054B BL4054B | Surface Mount
6 | X7 | 1 | JST | B2B-PH-K-S(LF)(SN) | Connector JST PH Series 2 Position 2 mm Pitch Through Hole Top Entry JST B2B-PH-K-S(LF)(SN) | Through Hole, Vertical
7 | X6 | 1 |  | GT-USB-7002A | Connector USB Type C Female 6Positions 0.5mm Right Angle SMD LCSCPN C963365 / C456012 USB-C Power | Through Hole + Surface Mount
8 | U4 | 1 |  | SY8089AAAC | DC/DC Regulator Step Down Synchronous 1A 1.5MHz SY8089AAAC | Surface Mount
9 | D1, D2, D4 | 3 | DIODES | 1N5819HW-7-F | Diode Schottky 1N5819 40V 1A SMD SOD123F LCSCPN C82544 1N5819HW-7-F | Surface Mount
10 | X1 | 1 | CVILUX | CH31072V200 | Header Male Vertical 2.54 mm 7 pins CVILUX CH31072V200 | Through Hole, Solder
11 | L1 | 1 |  | VLCF4020T-2R2N1R7 | Inductor 2.2uH 30% 2.19A 54mOhm SMD VLCF4020 LCSCPN C136245 2.2 uH | Surface Mount
12 | D5, D6, D7 | 3 |  | NCD0603G3 | LED Green SMD 0603 LED GRN | Surface Mount
13 | D3 | 1 |  | NCD0603R1 | LED Red SMD 0603 LED RED | Surface Mount
14 | U2 | 1 |  | 868MHz | LoRa SX1276 868MHz Wireless Transceiver Module LCSCPN C718834 SX1276 Wireless Module | Surface Mount
15 | U1 | 1 |  | ESP32-WROOM-32UE-N4 | MCU ESP32-WROOM-32UE-H4 ESP32-WROOM-32UE-N4 | Surface Mount
16 | Q1 | 1 |  | DMP3099L | MOSFET P-Channel DMP3099L 30V 65mOhm SMD SOT-23-3 DMP3099L-7 / WPM2015-3 | Surface Mount
17 | R10, R14 | 2 |  | ERJPA3J222V | Resistor 2.2k 5% 0.25W SMD 0603 2.2k | Surface Mount
18 | R2, R3, R17, R25 | 4 |  | AS03W4J0103T5E | Resistor 10k 5% 0.25W SMD 0603 10k | Surface Mount
19 | R18 | 1 |  | ERJ-UP3F4992V | Resistor 49.9k 1% 0.25W SMD 0603 49.9k | Surface Mount
20 | R19, R20, R21 | 3 |  | ERJPA3J221V | Resistor 220 ohm 5% 0.25W SMD 0603 220 | Surface Mount
21 | R11, R13 | 2 |  | ERJPA3F2203V | Resistor 220k 1% 0.25W SMD 0603 220k | Surface Mount
22 | R12, R15, R16 | 3 |  | ERJUP3F4703V | Resistor 470k 1% 0.25W SMD 0603 470k | Surface Mount
23 | SW1 | 1 | C&K | PTS636 SK25 SMTR LFS | Switch Tactile Top Actuated SPST N.O. LCSCPN C2689642 C&K Components PTS636SM43JSMTRLFS | Surface Mount
24 | X8 | 1 | Hirose | U.FL-R-SMT-1(10) | U.FL Coaxial Connector SMT 50 Ohm P/N U.FL-R-SMT-1(10) Hirose U.FL-R-SMT-1(10) | Surface Mount

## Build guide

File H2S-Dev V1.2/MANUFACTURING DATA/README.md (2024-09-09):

# Helium IoT Network Sensor Development board | H2S-Dev V1.2
## Manufacturing data

### General

Manufacturing data is required to establish the production process of a device. The minimum set of documents include graphical information representing the layers of the printed circuit board (PCB) layers, bill of materials (BOM) of the components, pick-place file with machine instructions of coordinates and rotation of each component to populate as well as assembly drawings of the component sketches on the board. Additional information may include 3D views, real pictures of a prototype and other information to ensure the quality manufacturing process.

A visualization of the H2S-Dev V1.2 production data - Gerber and Drill files including PCB edge, Top Layer, round and slot holes.

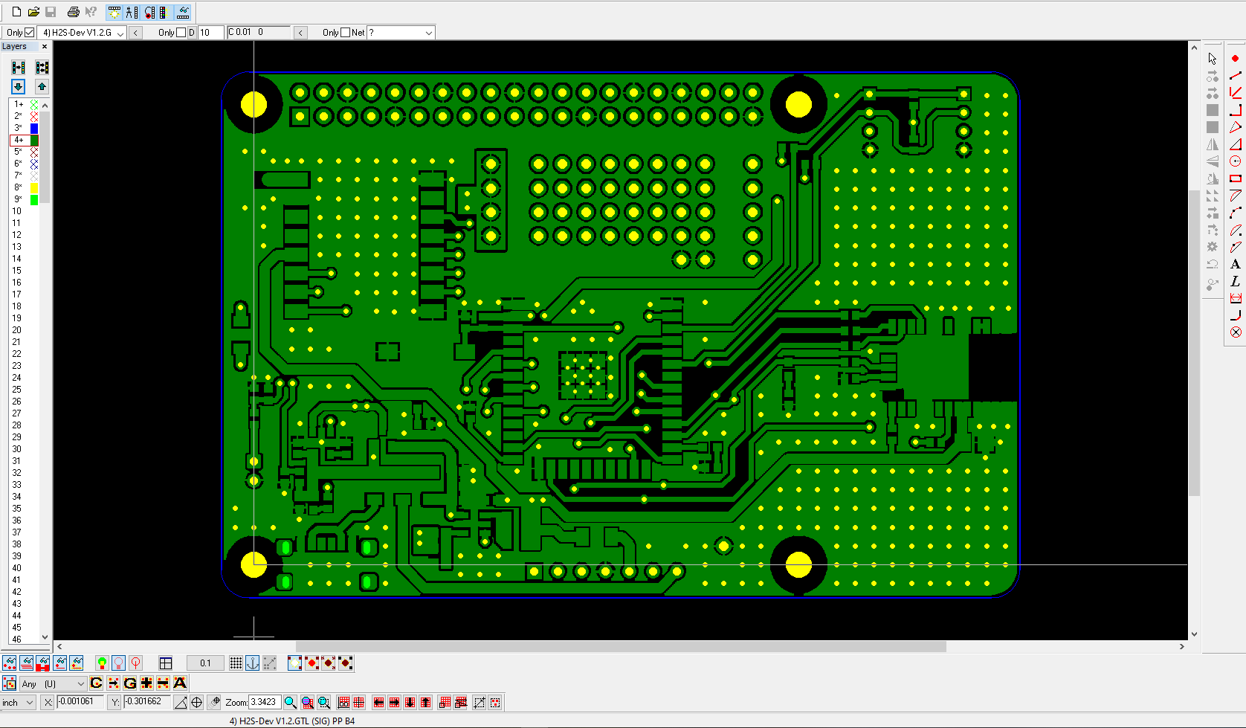
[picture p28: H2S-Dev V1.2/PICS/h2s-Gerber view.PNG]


Software used: [PentaLogix](https://www.pentalogix.com/t/software-products/viewmate) ViewMate 10 Free edition (old but nice to use!)

### Gerber files

Gerber files contain graphical information of the layers of the PCB. Copper layers, solder mask layers, silk screen print, PCB border and others are used to manufacture the board. Drill files contain information about the coordinates, size and type (round/slot) of the board holes. Gerber and drill files use a specific format related with the classical photo and drill machines used for manufacturing. Number precision (digits after the decimal point) is corresponding to precision of each process used to manufacture the real board.

### Pick-place data

Pick-place data is required for component placement. Each component designator is related to the part position on the board. Coordinates together with rotation information are provided for the component placement process. A careful inspection of the first populated sample before soldering is always a good practice.

### Bill of materials (BOM)

Bill of materials (BOM) is the actual list of components used. It contains important information for the exact type of each part defined by the component manufacturer and the corresponding part number. Specific parameters like voltage, current, material, etc. are also part of the BOM. It may also include other useful information as per PCB manufacturer's requirements.

### H2S-Dev V1.2 Variants

Helium IoT Network Sensor Development board (H2S-Dev V1.2) has several assembly variants suitable for a specific user application. The basic variant include ESP32 MCU, LoRa module, power supply as well as LED indicators and programming interface. The Full variant additionally incorporates a GNSS module and RaspberryPi interface connector. Variations of the MCU are also possible related to the RAM size required.

#
The hardware of the Helium IoT Network Sensor Development board V1.2 is designed as an open source project in the Altium Circuit Maker environment. To access the project follow the links below.

https://workspace.circuitmaker.com/Projects/Details/sivanovbg/H2S-Dev-V12

https://365.altium.com/files/AC741A32-A420-4803-868D-E6CB6756A587
#
More useful information: [H2S-Dev board V1.2 Hardware description and features](https://github.com/hobbyiot/HELIUM-SENSORS/blob/main/H2S-Dev%20V1.2/H2S-Dev%20board%20V1.2%20Hardware%20description%20and%20features.pdf)

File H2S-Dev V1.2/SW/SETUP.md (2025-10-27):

## H2S-Dev software environment setup

Under construction ...

1. Download and install Arduino
2. Install libraries: LMIC, DHT Sensors, TinyGPS
3. Setup lmic_project_config file according your region; set SX1276, enable interrupts
4. Download the sample code from that repo
5. Login into Helium console, create device and copy the credentials including APPEUI, DEVEUI and APPKEY into the example code config file
6. Connect your H2S-Dev to your computer using a standard ESP32 programmer
7. Compile and upload your code.
8. Watch the Helium console for data arriving! Enjoy!

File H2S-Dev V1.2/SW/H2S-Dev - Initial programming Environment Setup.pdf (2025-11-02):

# H2S-Dev board Tutorials

## LoRaWAN Helium network sensor development board

V1.2

# Initial programming environment setup

## 1. Abstract

H2S-Dev board is a ready-to-use, Open source hardware, Arduino compatible, LoRaWAN Helium network sensor development board. It is capable of implementing a number of sensor and positioning applications.

This tutorial will guide you through the initial setup of the programming environment to run an example code and start developing your own application with LoRaWAN Helium network sensor development board - the H2S-Dev board.

## 2. Install Arduino IDE

Install or update your Arduino IDE to the most recent version.

https://www.arduino.cc/en/software/

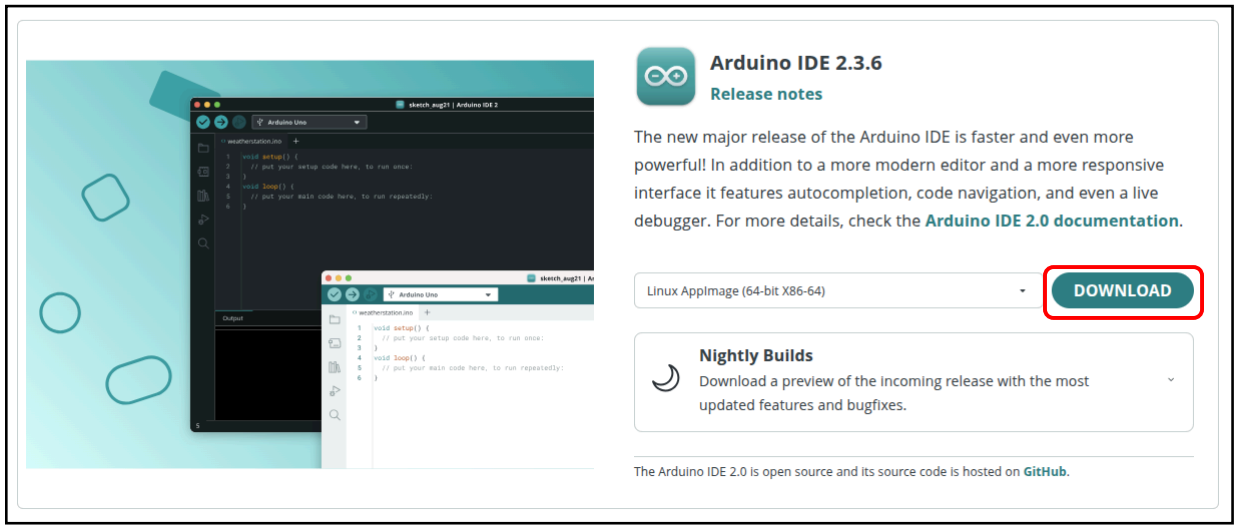
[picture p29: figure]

## 3. Install libraries required

A few libraries are required for the H2S-Dev board to start functioning.

### 3.1 Install LoRaWAN libraries for Arduino

As per our experience so far, we recommend the following libraries to be installed together with all the dependencies required.

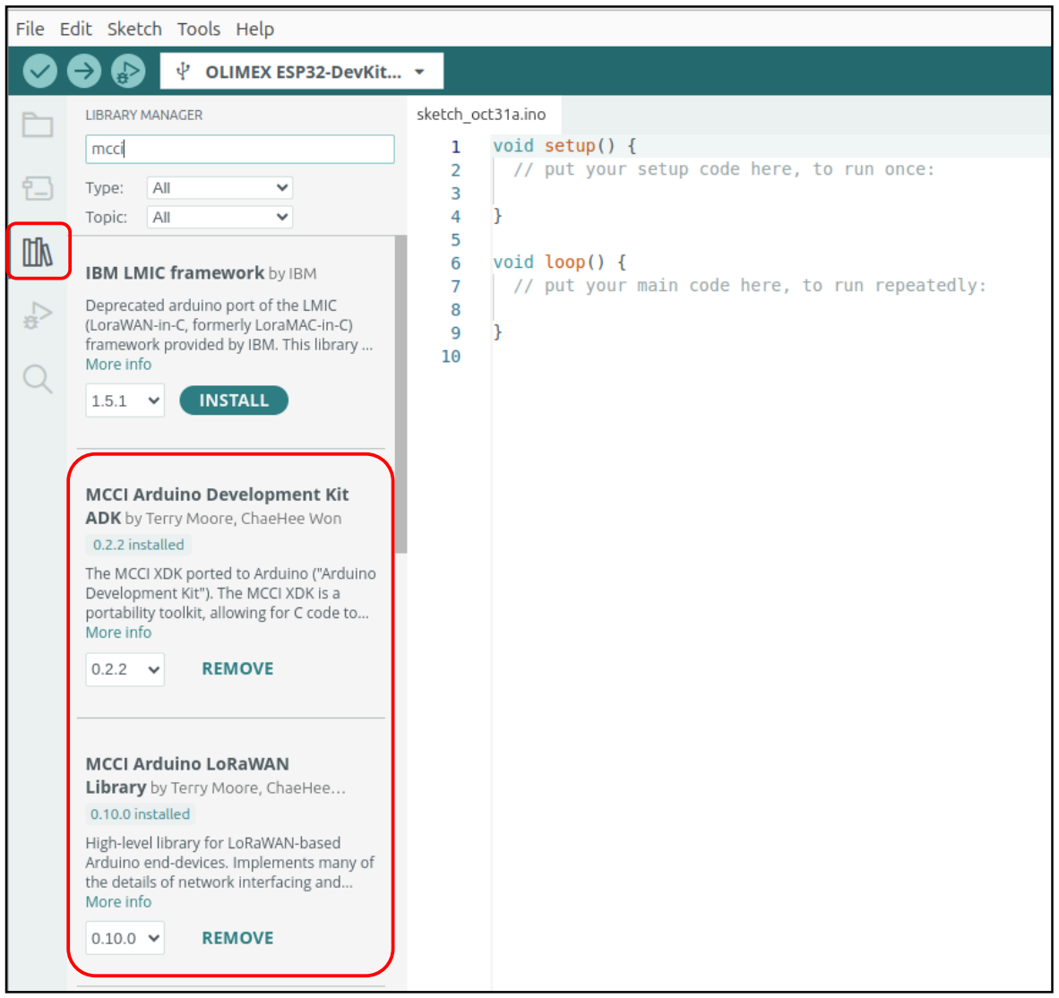
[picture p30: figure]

More information: https://github.com/hobbyiot/HELIUM-SENSORS

### 3.2 Install DHTxx library

For a specific application example - reading temperature and humidity from a DHT11 sensor, you will also need to install the corresponding library support. We recommend the THT sensor library from Adafruit. Please select the most recent version and install it.

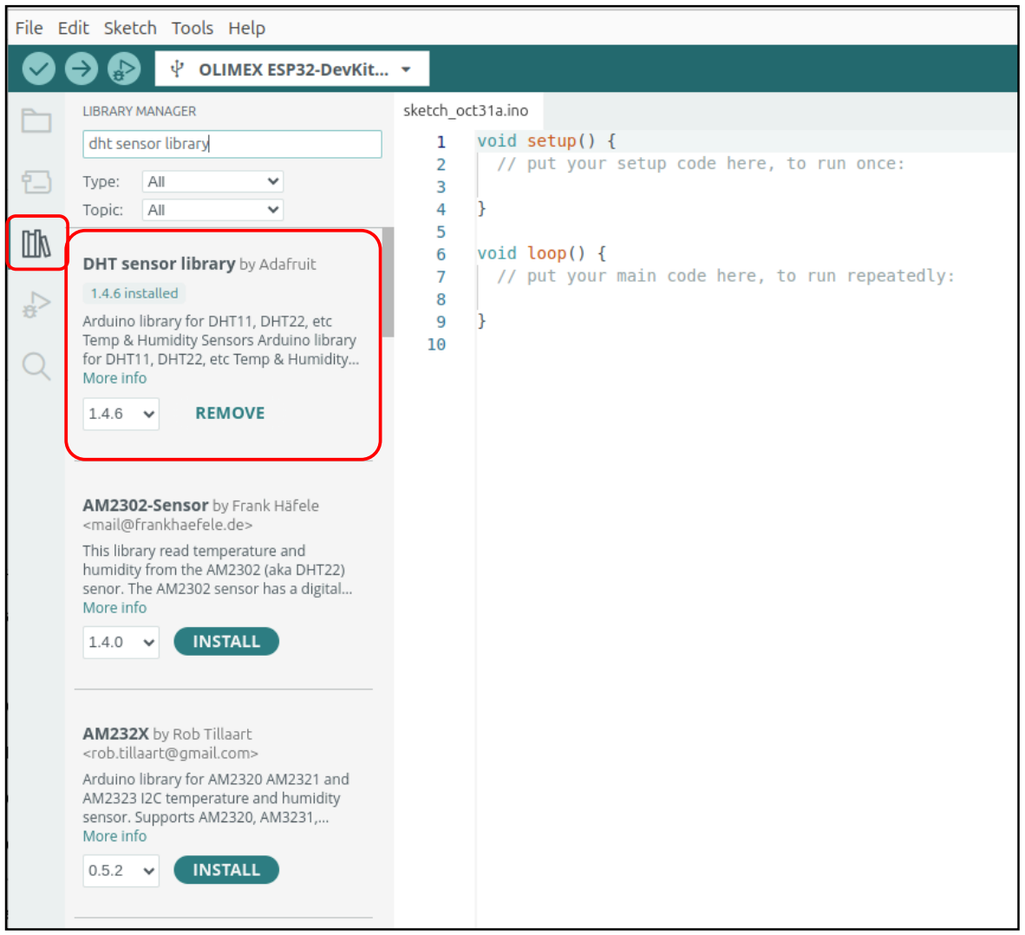
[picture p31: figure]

### 4. Configure lmic_project_config.h

An important thing to set up before starting to use the H2S-Dev board is to correctly configure the project parameters for LoRa communication. Please find the project_config folder within the Arduino libraries installed as shown in the picture below and open the lmic_project_config.h

For a typical Linux installation the path to that file could be as follows:

/home/user/Arduino/libraries/MCCI_LoRaWAN_LMIC_library/project_config

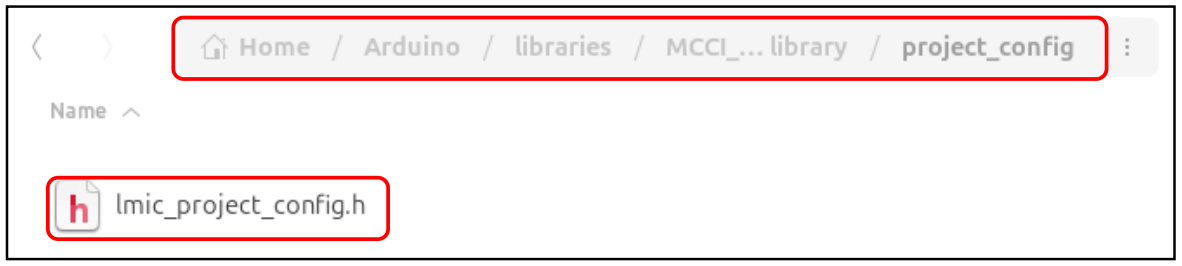
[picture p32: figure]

Open the file lmic_project_config.h and set by comment/uncomment using ‘#’:

- Frequency | set according to your country region;
- Chipset | select CFG_sx1276_radio;
- Interrupts | allow using interrupts by LMIC_USE_INTERRUPTS

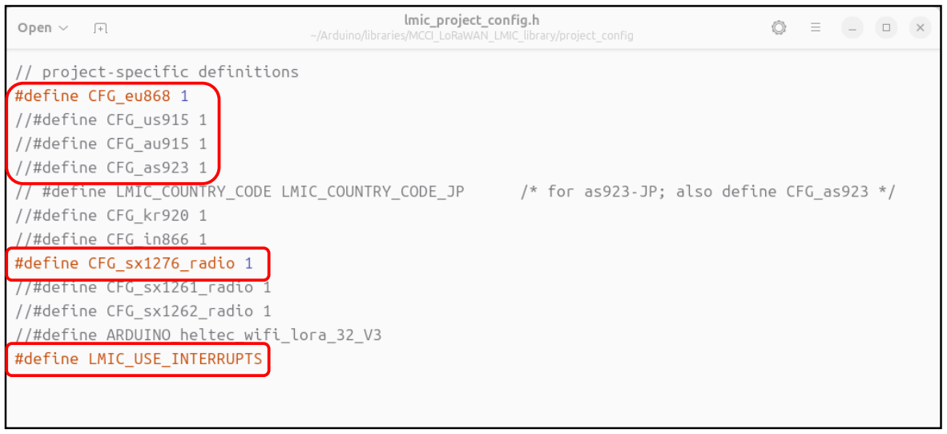
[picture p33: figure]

### 5. Download the example code from the project Github repository

https://github.com/hobbyiot/HELIUM-SENSORS/blob/main/H2S-Dev%20V1.2/SW/H2S-DEV-TH S-V0.5.ino (https://github.com/hobbyiot/HELIUM-SENSORS/blob/main/H2S-Dev%20V1.2/SW/H2S-DEV-THS-V0.5.ino)

The example code provided uses a DHT11 temperature and humidity sensor and sends data over the Helium network in a specific format according to the Helium network requirements. DHT11 is programmed to be connected to GPIO13 in the example but you can change the configuration as per your needs.

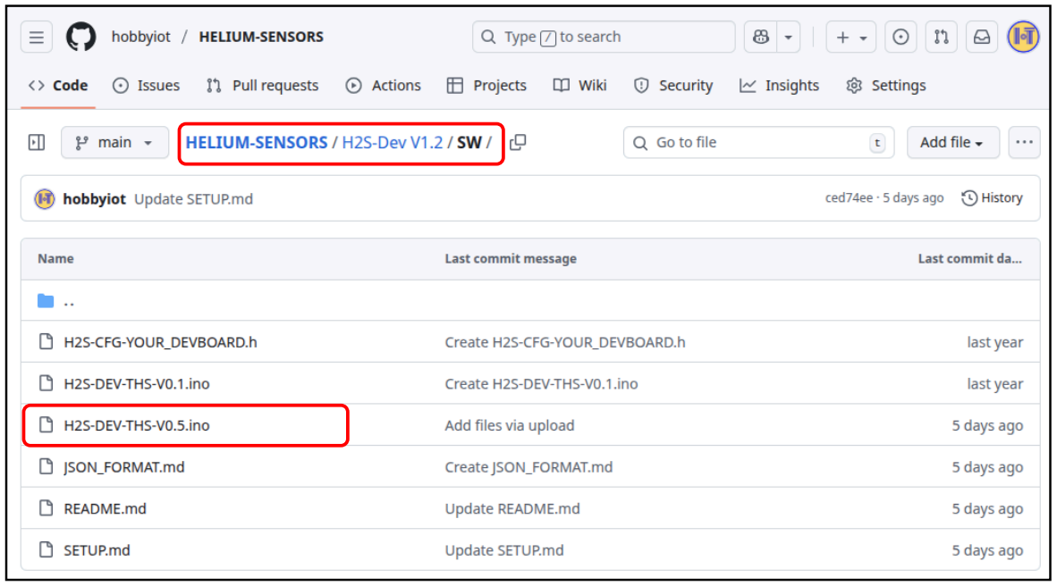
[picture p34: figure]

The algorithm periodically reads the data from the connected DHT11 sensor. Temperature and humidity values are then combined into a specific JSON structure and sent over the Helium network.

The specific JSON format and various ways of receiving and using the data are all described in separate documents.

Generally, the data path is constructed as a set of logical rules (flows) within the Helium console environment and could be directed to a shared spreadsheet, MQTT broker, etc.

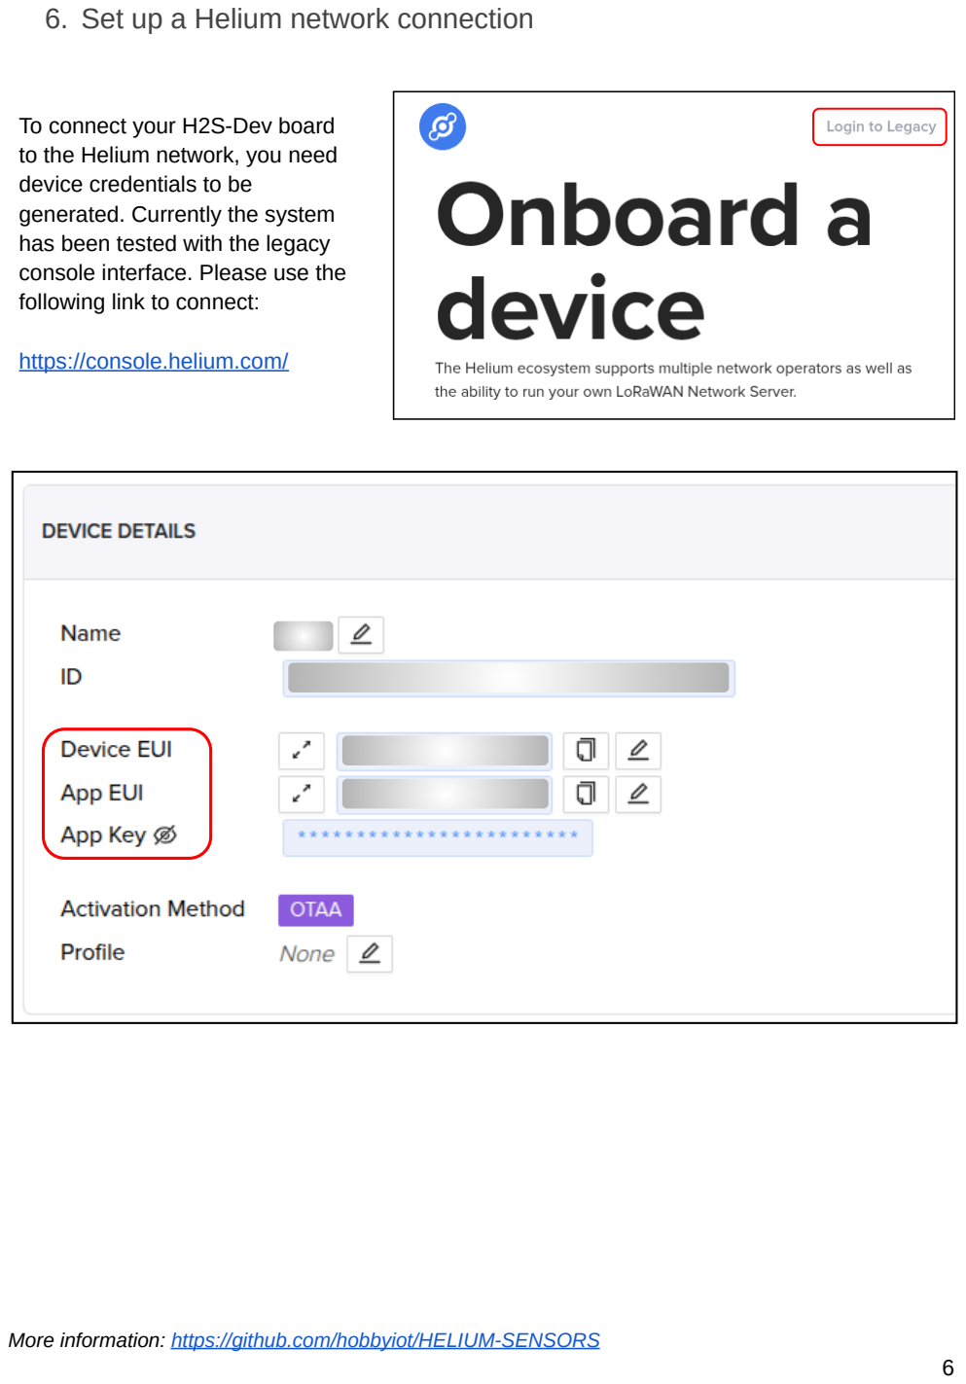
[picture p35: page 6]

### 6. Set up a Helium network connection

To connect your H2S-Dev board
to the Helium network, you need device credentials to be
generated. Currently the system has been tested with the legacy console interface. Please use the following link to connect:

https://console.helium.com/

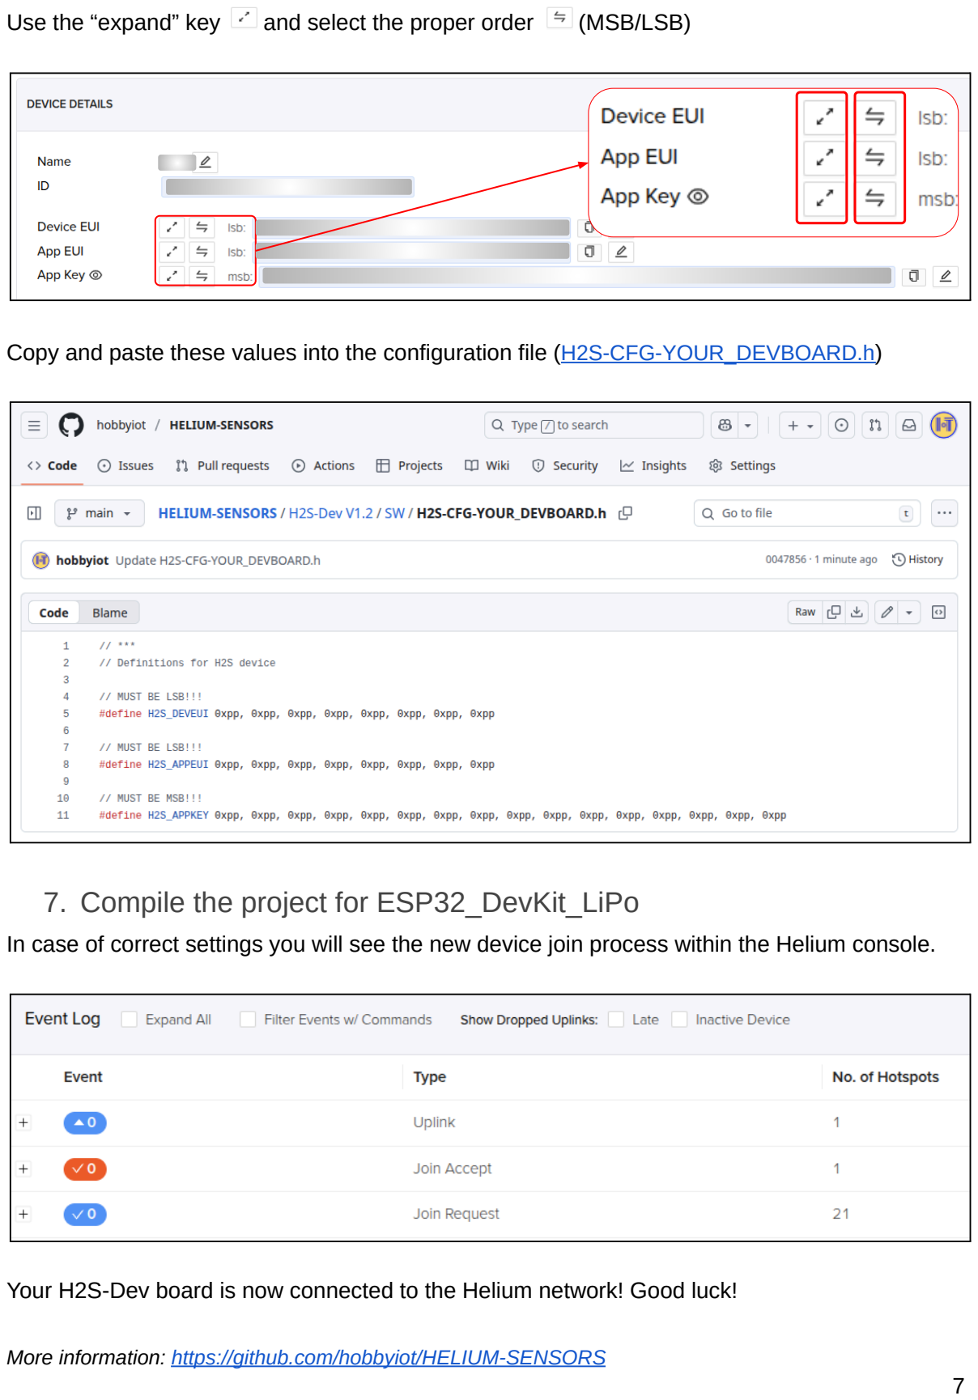
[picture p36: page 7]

Use the “expand” key | and select the proper order | (MSB/LSB)

Copy and paste these values into the configuration file (H2S-CFG-YOUR_DEVBOARD.h) (https://github.com/hobbyiot/HELIUM-SENSORS/blob/main/H2S-Dev%20V1.2/SW/H2S-CFG-YOUR_DEVBOARD.h)

### 7. Compile the project for ESP32_DevKit_LiPo

In case of correct settings you will see the new device join process within the Helium console.

Your H2S-Dev board is now connected to the Helium network! Good luck!

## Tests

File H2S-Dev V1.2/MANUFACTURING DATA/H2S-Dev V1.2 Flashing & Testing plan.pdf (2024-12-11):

### H2S-Dev V1.2 Flashing and testing instructions

I. Tools and accessories required for the test
# | Description | Example picture

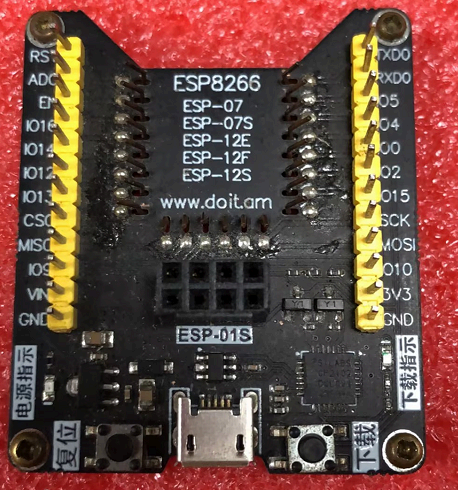
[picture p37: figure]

1 | External ESP32 flasher/programmer
2 | LiPo battery,about 50% charged, with 2-pin 2 mm JST socket connector

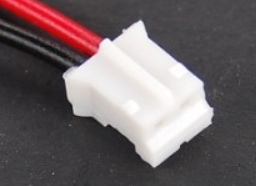
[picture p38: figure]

3 | USB-C 5V power source with current limit of 1A | No picture required
II. | Flashing the ESP32

Flashing the ESP32 is based on an external programmer as the one shown above.

1. Use the bin file “H2S-Dev_V1.2_Basic_Test.bin” provided.
2. Set the starting address to 0x0000.
3. ESP32 is now ready for soldering.

III. Testing the product

Summary
Testing the product is semi-automated by the software flashed into the ESP32 in step I-2 above. The very first step is to connect the LoRa antenna. After that one should connect the USB-C power source and later the battery watching for several LED patterns.

Test steps

# | Action | Picture / resolution | Result

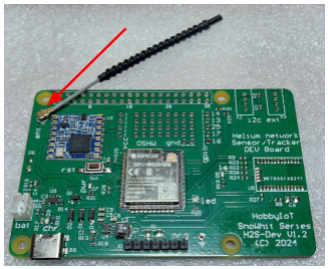
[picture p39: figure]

1 | Connect the X8-1 (LoRa antenna) into the ‘ant’ (X8) socket as shown on the picture

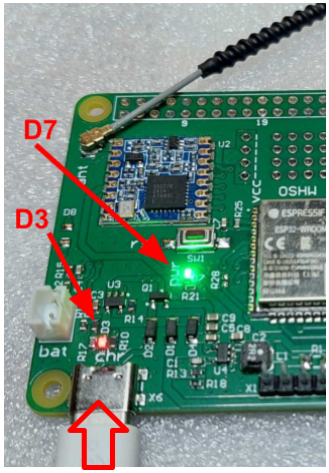
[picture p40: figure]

2 | Connect the USB-C 5V power source into the USB-C (X6) connector
| Watch D3 (Red LED) and D7 (Green LED) should both be ON permanently

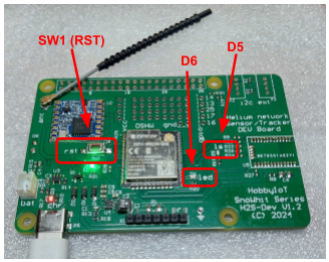
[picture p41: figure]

3 | Press SW1 (RST) button and right after that watch D5 (Green LED) and D6 (Green LED) behaviour exactly as follows:
| ● D5+D6 - flash three times together ● D5 goes off ● D6 flashes once ● D6 flashes twice

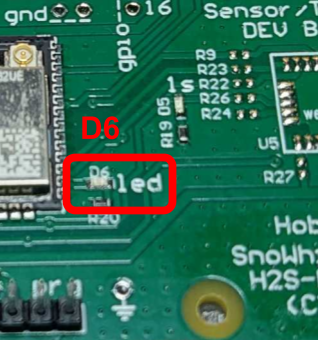
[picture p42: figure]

4 | D6 continues flashing twice - the product is now waiting for battery
5 | Connect the LiPo battery and watch the D3 (Red LED) and D6 (Green LED) behaviour exactly as follows: ● D3 goes nearly OFF ● D6 flashes 3 times ● D6 continues flashing fast - once per second

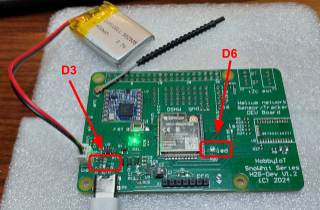
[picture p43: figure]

6 | D6 is flashing fast - once per second | Test is completed

7 | D6 is dimming periodically | Something is wrong with the board
8 | Overall result | PASS/FAIL

Final steps
Disconnect the battery
Disconnect the USB-C
DO NOT disconnect the antenna (X8-1)

End of document.

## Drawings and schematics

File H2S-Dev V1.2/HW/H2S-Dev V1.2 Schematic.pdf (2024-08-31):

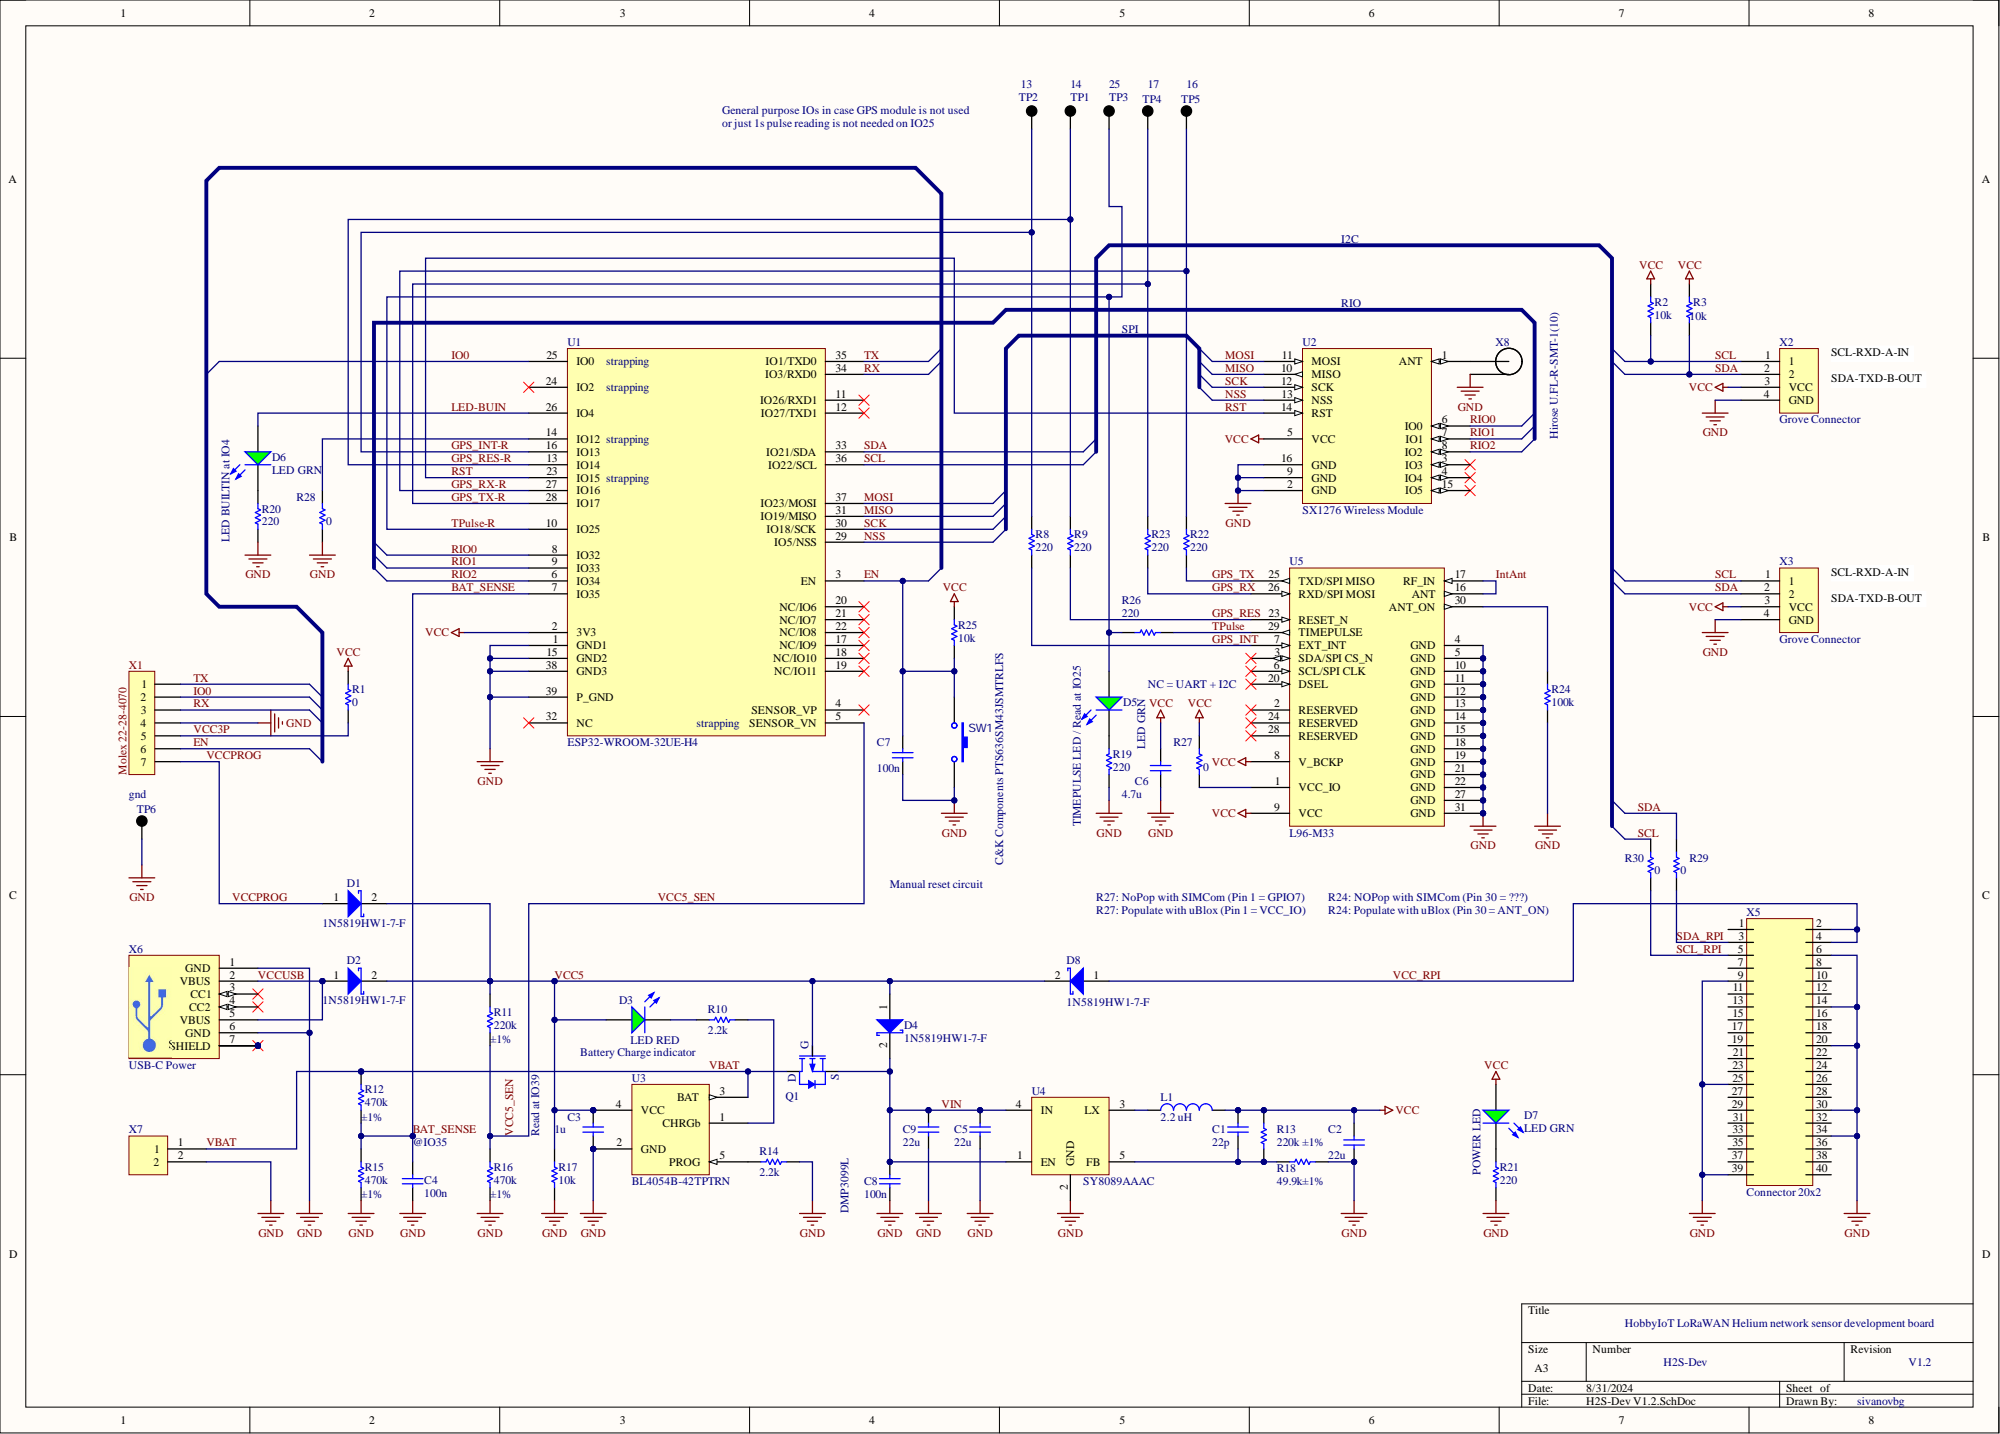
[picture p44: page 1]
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

TIMEPULSE LED / Read at IO25

R27: NoPop with SIMCom (Pin 1 = GPIO7)
R27: Populate with uBlox (Pin 1 = VCC_IO)

R24: NOPop with SIMCom (Pin 30 = ???)
R24: Populate with uBlox (Pin 30 = ANT_ON)

HobbyIoT LoRaWAN Helium network sensor development board

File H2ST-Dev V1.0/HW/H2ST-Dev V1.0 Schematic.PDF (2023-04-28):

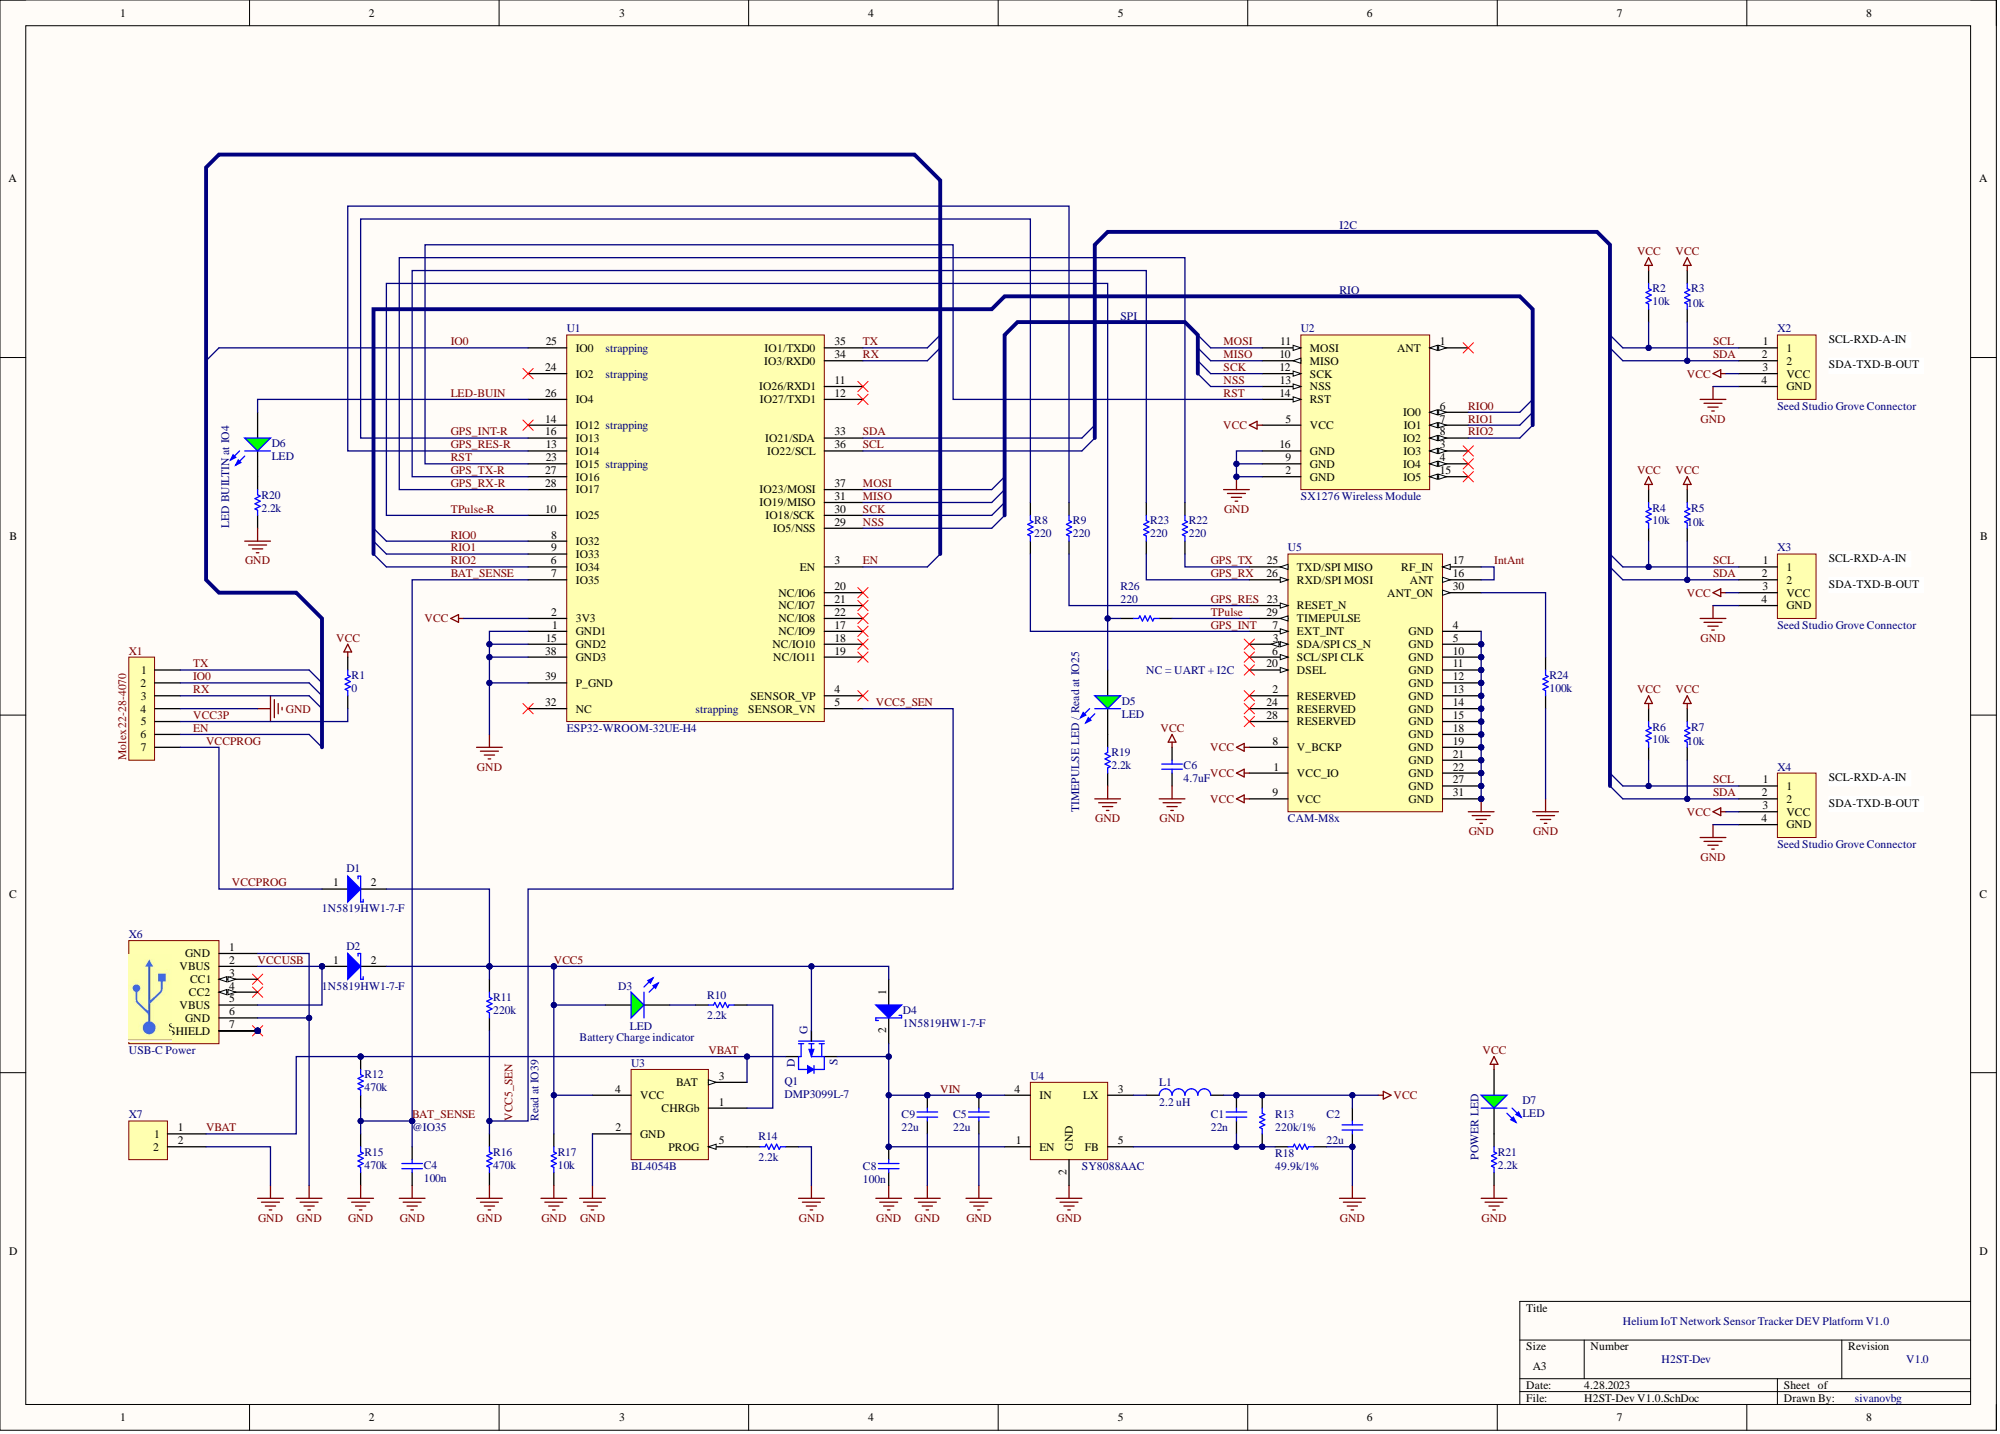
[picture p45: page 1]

Seed Studio Grove Connector

TIMEPULSE LED / Read at IO25

Battery Charge indicator | VBAT

R12 470k | BAT_SENSE | U3

Helium IoT Network Sensor Tracker DEV Platform V1.0

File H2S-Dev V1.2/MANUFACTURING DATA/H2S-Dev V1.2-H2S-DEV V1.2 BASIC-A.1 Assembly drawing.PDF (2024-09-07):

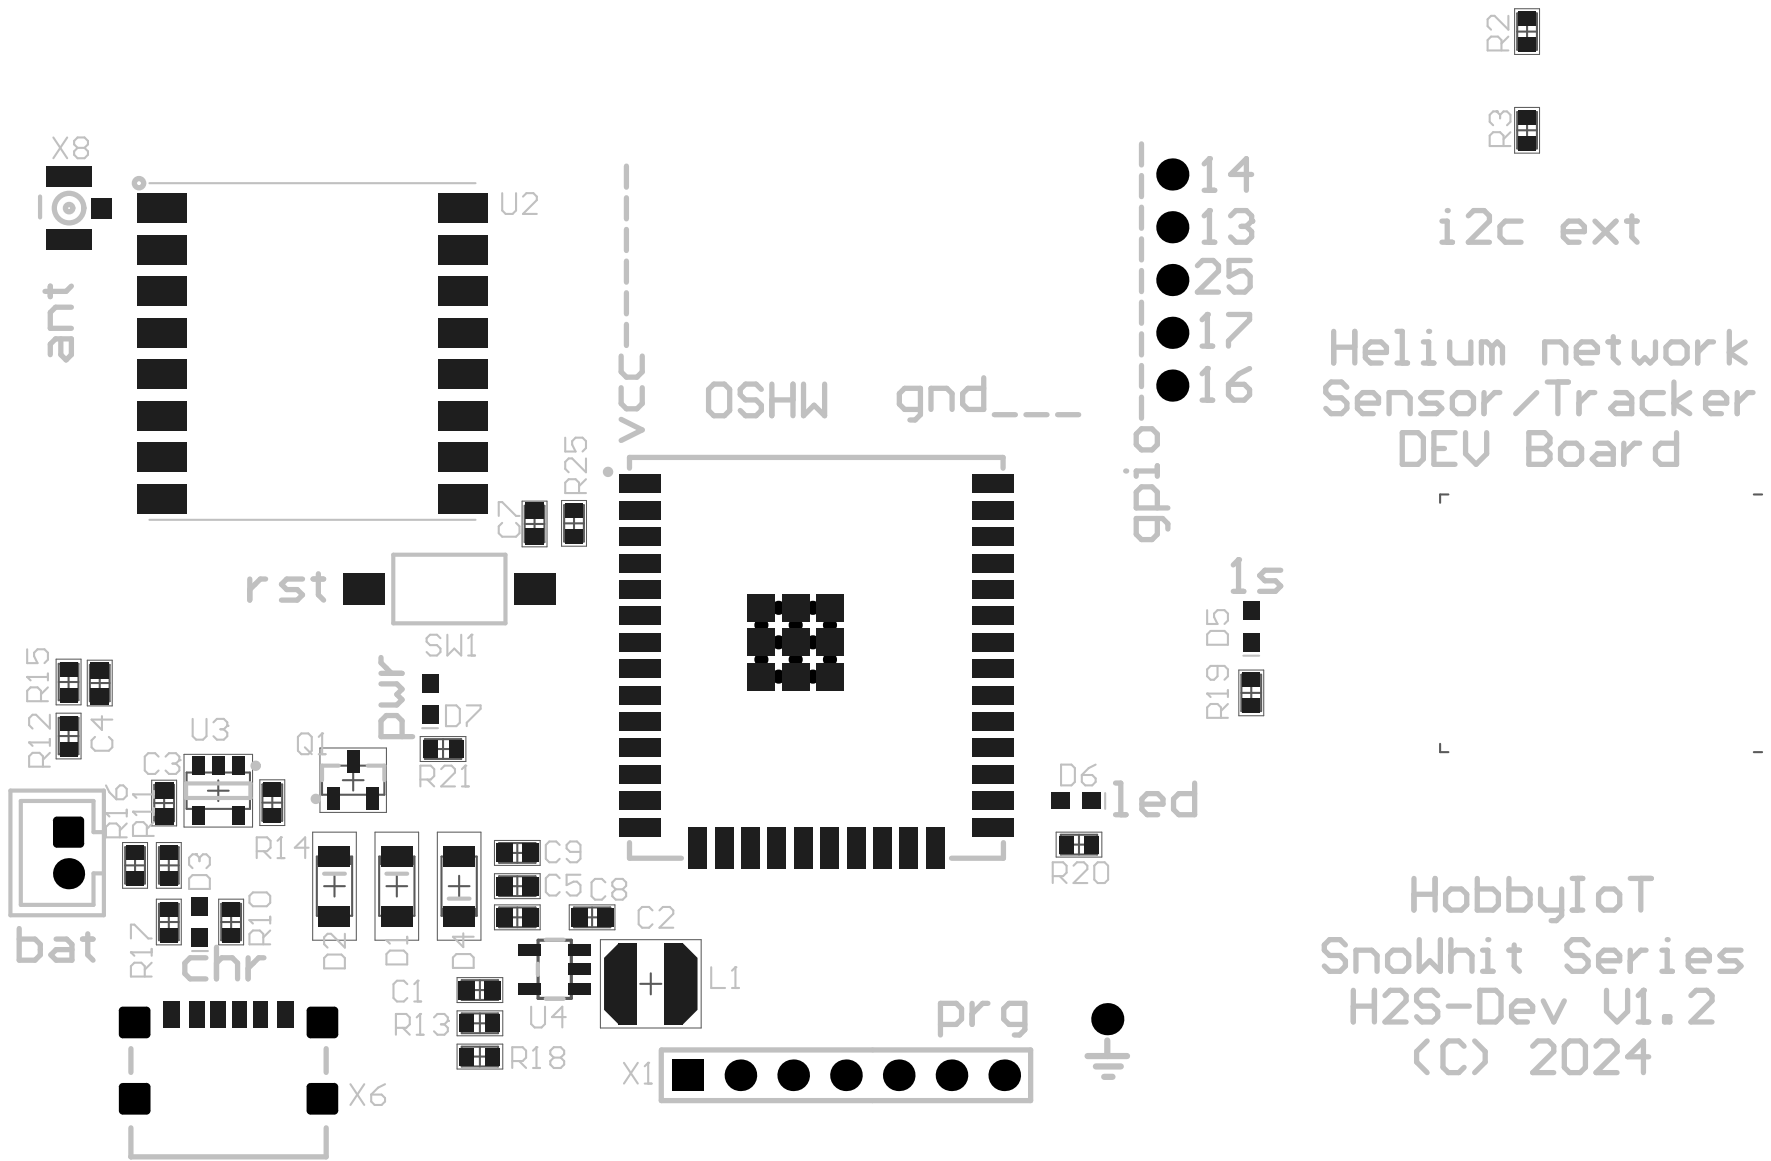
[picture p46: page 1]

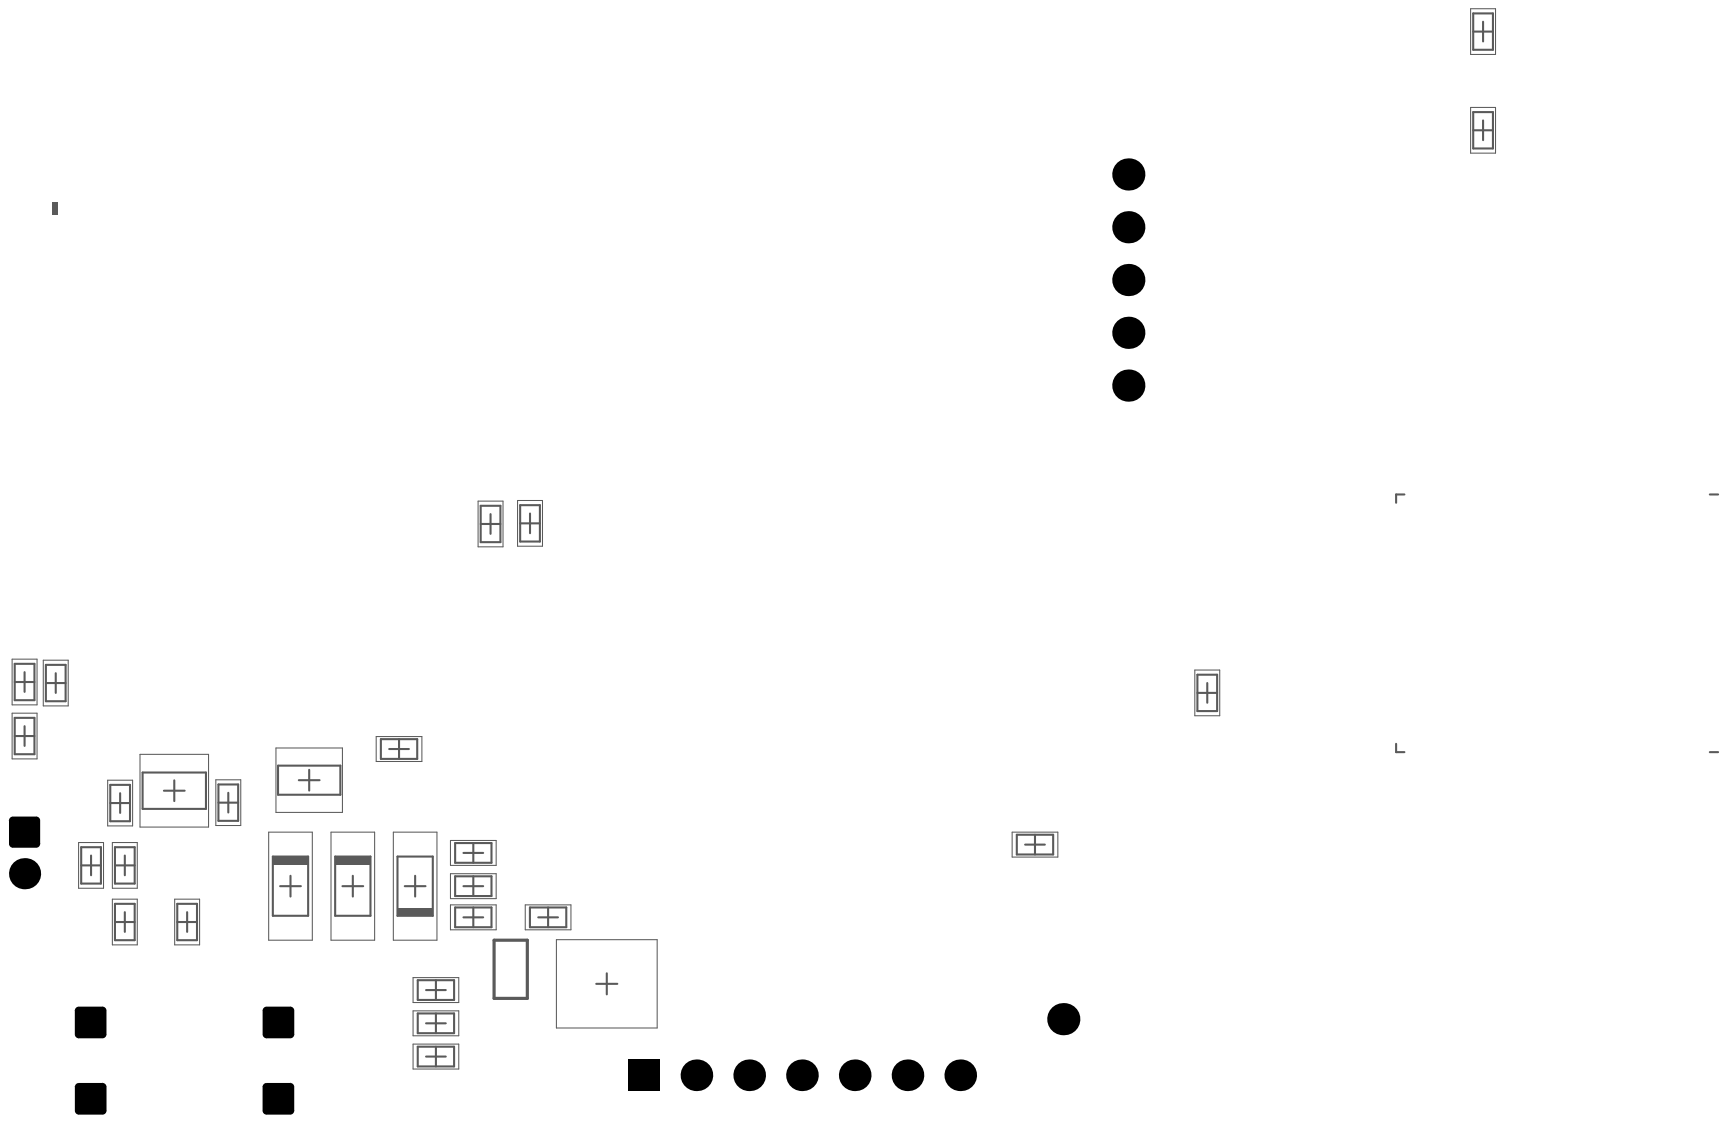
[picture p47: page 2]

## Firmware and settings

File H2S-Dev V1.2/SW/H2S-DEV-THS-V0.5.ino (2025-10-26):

/*******************************************************************************
 *
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
 * NO WARRANTY OF ANY KIND IS PROVIDED.
 *
 * This example sends a valid LoRaWAN packet over The Helium network
 * with a payload containing temperature and humidity data
 * as they are read from a DHT11 sensor, connected to GPIO13
 * using frequency and encryption settings according your region.
 *
 * The data format and the JSON script for decoding it
 * are described in separate article in the project's GitHub
 * (https://github.com/hobbyiot/HELIUM-SENSORS)
 *
 * This uses OTAA (Over-the-air activation), where where a DevEUI and
 * application key is configured, which are used in an over-the-air
 * activation procedure where a DevAddr and session keys are
 * assigned/generated for use with all further communication.
 *
 * To use this sketch, first register your application and device with
 * The Helium network console (https://console.helium.com/welcome)
 * to set or generate an AppEUI, DevEUI and AppKey.
 * Multiple devices can use the same AppEUI, but each device has its own
 * DevEUI and AppKey.
 *
 * ****** Do not forget to define the radio type correctly in config.h !!! ******
 *
 * Copyright (c) 2025 HobbyIoT (S. Ivanov)
 * Copyright (c) 2015 Thomas Telkamp and Matthijs Kooijman
 *
 *******************************************************************************/


#include "H2S-CFG-YOUR_DEVBOARD.h"

#include <lmic.h>
#include <hal/hal.h>
#include <SPI.h>
#include "DHT.h"

#define DHTPIN 13
#define DHTTYPE DHT11

#define THDATA '9'

#define DTYPE THDATA

DHT dht(DHTPIN, DHTTYPE);

// DEVEUI MUST BE LSB!!!
static const u1_t PROGMEM DEVEUI[8]={ H2S_DEVEUI };
void os_getDevEui (u1_t* buf) { memcpy_P(buf, DEVEUI, 8);}

// APPEUI MUST BE LSB!!!
static const u1_t PROGMEM APPEUI[8]={ H2S_APPEUI };
void os_getArtEui (u1_t* buf) { memcpy_P(buf, APPEUI, 8);}

// APPKEY MUST BE *MSB*!!!
static const u1_t PROGMEM APPKEY[16] = { H2S_APPKEY };
void os_getDevKey (u1_t* buf) {  memcpy_P(buf, APPKEY, 16);}

static uint8_t mydata_t[7], mydata_h[7], packet[16];
char mydatat[7],mydatah[7];

float t, h;

u1_t ptr;

static osjob_t sendjob;

// Schedule TX every this many seconds (might become longer due to duty
// cycle limitations).
const unsigned TX_INTERVAL = 300;

// Pin mapping
const lmic_pinmap lmic_pins = {
    .nss = 5,
    .rxtx = LMIC_UNUSED_PIN,
    .rst = 15,
    .dio = {32, 33, 34}, // 25, 26, 27
};

void onEvent (ev_t ev) {
    Serial.print(os_getTime());
    Serial.print(": ");
    switch(ev) {
        case EV_SCAN_TIMEOUT:
            Serial.println(F("EV_SCAN_TIMEOUT"));
            break;
        case EV_BEACON_FOUND:
            Serial.println(F("EV_BEACON_FOUND"));
            break;
        case EV_BEACON_MISSED:
            Serial.println(F("EV_BEACON_MISSED"));
            break;
        case EV_BEACON_TRACKED:
            Serial.println(F("EV_BEACON_TRACKED"));
            break;
        case EV_JOINING:
            Serial.println(F("EV_JOINING"));
            break;
        case EV_JOINED:
            Serial.println(F("EV_JOINED"));

            // Disable link check validation (automatically enabled
            // during join, but not supported by TTN at this time).
            LMIC_setLinkCheckMode(0);
            break;
        case EV_RFU1:
            Serial.println(F("EV_RFU1"));
            break;
        case EV_JOIN_FAILED:
            Serial.println(F("EV_JOIN_FAILED"));
            break;
        case EV_REJOIN_FAILED:
            Serial.println(F("EV_REJOIN_FAILED"));
            break;
            break;
        case EV_TXCOMPLETE:
            Serial.println(F("EV_TXCOMPLETE (includes waiting for RX windows)"));
            if (LMIC.txrxFlags & TXRX_ACK)
              Serial.println(F("Received ack"));
            if (LMIC.dataLen) {
              Serial.println(F("Received "));
              Serial.println(LMIC.dataLen);
              Serial.println(F(" bytes of payload"));
            }
            // Schedule next transmission
            os_setTimedCallback(&sendjob, os_getTime()+sec2osticks(TX_INTERVAL), do_send);
            break;
        case EV_LOST_TSYNC:
            Serial.println(F("EV_LOST_TSYNC"));
            break;
        case EV_RESET:
            Serial.println(F("EV_RESET"));
            break;
        case EV_RXCOMPLETE:
            // data received in ping slot
            Serial.println(F("EV_RXCOMPLETE"));
            break;
        case EV_LINK_DEAD:
            Serial.println(F("EV_LINK_DEAD"));
            break;
        case EV_LINK_ALIVE:
            Serial.println(F("EV_LINK_ALIVE"));
            break;
         default:
            Serial.println(F("Unknown event"));
            break;
    }
}

void do_send(osjob_t* j){
    // Check if there is not a current TX/RX job running
    if (LMIC.opmode & OP_TXRXPEND) {
        Serial.println(F("OP_TXRXPEND, not sending"));
    } else {
        // Prepare upstream data transmission at the next possible time.
        t = dht.readTemperature();
//        delay(1000);
        h = dht.readHumidity();
//        delay(1000);
        dtostrf(t,0,2,mydatat);
        dtostrf(h,0,2,mydatah);
        Serial.println();
        Serial.print("Temperature: ");
        Serial.println(t);
        Serial.print("Humidity: ");
        Serial.println(h);
        Serial.println();

        for(int i=0;i<7;i++) {
          mydata_t[i]=mydatat[i];
          mydata_h[i]=mydatah[i];
        }

        ptr = 0;

        packet[ptr++] = '1'; // channel 1
        packet[ptr++] = DTYPE;

        for(;ptr<9;ptr++) {
          packet[ptr] = mydata_t[ptr-2];
        }
        for(;ptr<16;ptr++) {
          packet[ptr] = mydata_h[ptr-9];
        }
        packet[ptr] = 0x00; // End of packet
        Serial.println("*** Packet prepared! ***");
        LMIC_setTxData2(1, packet, sizeof(packet), 0);
        Serial.println(F("Packet queued"));
    }
    // Next TX is scheduled after TX_COMPLETE event.
}

void setup() {

    Serial.begin(115200);
    while(!Serial);

    Serial.println();
    Serial.println("**          THE HELIUM Network BEAR Node (c) HobbyIoT          **");
    Serial.println("*        With ESP32 Module + LoRa module based on SX1276        *");
    Serial.println("Example code by IBM LMIC framework TTN-OTAA set up for EU 868 MHz");
    Serial.println("                    *** H2S-DEV-THS-V0.5 ***                     ");
    Serial.println("**=============================================================**");    
    Serial.println();
    
    Serial.println(F("Starting"));
    
    dht.begin();

    #ifdef VCC_ENABLE
    // For Pinoccio Scout boards
    pinMode(VCC_ENABLE, OUTPUT);
    digitalWrite(VCC_ENABLE, HIGH);
    delay(1000);
    #endif

    // LMIC init
    os_init();
    // Reset the MAC state. Session and pending data transfers will be discarded.
    LMIC_reset();
    
    // allow much more clock error than the X/1000 default. See:
    // https://github.com/mcci-catena/arduino-lorawan/issues/74#issuecomment-462171974
    // https://github.com/mcci-catena/arduino-lmic/commit/42da75b56#diff-16d75524a9920f5d043fe731a27cf85aL633
    // the X/1000 means an error rate of 0.1%; the above issue discusses using
    // values up to 10%. so, values from 10 (10% error, the most lax) to 1000
    // (0.1% error, the most strict) can be used.
    LMIC_setClockError(1 * MAX_CLOCK_ERROR / 40);
    

    // Sub-band 2 - Helium Network
//     LMIC_selectSubBand(1); // zero indexed - for US band (915 MHz)
    LMIC_setupBand(1, 14, 100); //1,14,100

    // bit_t LMIC_setupBand (u1_t bandidx, s1_t txpow, u2_t txcap);
    // bandidx = 1, txpow = 14, txcap = 100 = 1%
    
    LMIC_setLinkCheckMode(0);
    LMIC_setDrTxpow(DR_SF7, 14); //14

    // Start job (sending automatically starts OTAA too)
    do_send(&sendjob);
}

void loop() {
    os_runloop_once();
}

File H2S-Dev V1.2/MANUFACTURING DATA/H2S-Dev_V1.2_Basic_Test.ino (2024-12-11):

// Helium IoT Network Sensor Development board
// H2S-Dev V1.2 Basic
// Basic automated test software written in Arduino Environment

// This software and the corresponding hardware are open source under MIT License

// Copyright (C) HobbyIoT

#define LED_BUILTIN 4
#define LED_1PPS 25

#include <SPI.h>
#include <LoRa.h>

void setup() {

  Serial.begin(115200);
  while(!Serial);

  LoRa.setPins(5, 15, 32); // set CS, reset, IRQ pin

  pinMode(4, OUTPUT);
  pinMode(25, OUTPUT);
  pinMode(35, INPUT); // Battery sense input
  pinMode(39, INPUT); // USB-C/5V sense input

  Serial.begin(115200);
}

void loop() {

  float vcc5 = 0, vbat = 0;
// By default the test result is 0 = 'failed'
  char result = 0;

  Serial.println();
  Serial.println("**=============================================================**");
  Serial.println("**         Helium IoT Network Sensor Development board         **");
  Serial.println("*                     H2S-Dev V1.2 Basic                       **");
  Serial.println("*             A simple automated test software                  *");
  Serial.println("*        https://github.com/hobbyiot/HELIUM-SENSORS/            *");
  Serial.println("*                https://www.hobbyiot.net/                      *");
  Serial.println("**=============================================================**");    

  Serial.println();

// Welcome blink

  for(char i=0;i<3;i++) {
    digitalWrite(LED_BUILTIN,HIGH); digitalWrite(LED_1PPS,HIGH); delay(100);
    digitalWrite(LED_BUILTIN,LOW); digitalWrite(LED_1PPS,LOW); delay(300);
  }
  
delay(1000);

  Serial.println(F("Testing board modules..."));
  Serial.println();

  vcc5 = analogRead(39)/819;
  Serial.print("Input voltage:   ");
  Serial.print(vcc5);
  Serial.print(" V ... ");
  
  if (vcc5 > 4.5) {
    result++;
    Serial.println("PASS");
    digitalWrite(LED_BUILTIN,HIGH); delay(100); digitalWrite(LED_BUILTIN,LOW);
  } else {
    Serial.println("FAIL");
    // digitalWrite(LED_BUILTIN,HIGH); delay(300); digitalWrite(LED_1PPS,LOW);
  }
  delay(1000);

  vbat = analogRead(35)/589;
    Serial.print("Charger voltage: ");
    Serial.print(vbat);
    Serial.print(" V ... ");
  if (vbat < 2.2) {
    result++;
    Serial.println("PASS");
    delay(500);
    Serial.print("Connect battery: ");
    do {
      digitalWrite(LED_BUILTIN,HIGH); delay(100); digitalWrite(LED_BUILTIN,LOW); delay(300);
      digitalWrite(LED_BUILTIN,HIGH); delay(100); digitalWrite(LED_BUILTIN,LOW);
      delay(1000);
      vbat = analogRead(35)/589;
    } while (vbat < 3.5);

    Serial.print(vbat);
    Serial.print(" V ... ");
    
    result++;
    Serial.println("PASS");
    digitalWrite(LED_BUILTIN,HIGH); delay(100); digitalWrite(LED_BUILTIN,LOW); delay(300);
    digitalWrite(LED_BUILTIN,HIGH); delay(100); digitalWrite(LED_BUILTIN,LOW);
  } else {
    Serial.println("FAIL");
    // digitalWrite(LED_BUILTIN,HIGH); delay(300); digitalWrite(LED_1PPS,LOW);
  }
  delay(1000);

    if (!LoRa.begin(868E6)) {         // initialize ratio at 868 MHz
    Serial.println("LoRa init failed. Check your connections.");
    }
    else
    {
      result++;
      Serial.println("Checking LoRa module    ... PASS");
      digitalWrite(LED_BUILTIN,HIGH); delay(100); digitalWrite(LED_BUILTIN,LOW); delay(300);
      digitalWrite(LED_BUILTIN,HIGH); delay(100); digitalWrite(LED_BUILTIN,LOW); delay(300);
      digitalWrite(LED_BUILTIN,HIGH); delay(100); digitalWrite(LED_BUILTIN,LOW);
    }

//    LoRa.dumpRegisters(Serial);

  if(result == 4) {
    Serial.println("--------------------------------");
    Serial.println("Total result            ... PASS");
    Serial.println();
    Serial.println("Test finished. Press RESET to start over... ");
    Serial.println("... or have fun with your new board!");
    
delay(1000);

    while(1)
    //Flash LED for test PASS
      for(char i=0;i<3;i++) {
      digitalWrite(LED_BUILTIN,HIGH); delay(50); digitalWrite(LED_BUILTIN,LOW); delay(1000);
      }
  } else {
    Serial.println("--------------------------------");
    Serial.println("Total result:           ... FAIL");
    Serial.println();
    Serial.println("Test finished. Press RESET to start over... ");
    while(1)
    //Blink LED for test FAIL
      for(char i=255;i>0;i--) {
      analogWrite(LED_BUILTIN,i);
      delay(8);
    }
    delay(500);
  }
}

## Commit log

2023-10-23 H2S-Dev V1.1 Schematic
2023-10-25 Production data
    [H2S-Dev V1.1.GBL, H2S-Dev V1.1.GBP, H2S-Dev V1.1.GBS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]
2024-11-30 Add files via upload
    Updated information
    [H2S-Dev V1.2 (H2S-Dev V1.2 Basic) BOM.xls]
